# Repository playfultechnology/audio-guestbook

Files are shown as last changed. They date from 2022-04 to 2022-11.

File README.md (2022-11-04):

# audio-guestbook
The audio guestbook is a converted telephone handset that guests can use to leave recorded messages at weddings, parties and other events, as sold by companies such as "After the Tone", "Fête Fone", "Life on Record", "At the Beep", and others.

Watch the full step-by-step tutorial on how to use the code here to build your own at https://youtu.be/dI6ielrP1SE
 
 ---
## Disabled MTP during recording
In some cases, the MTP capability (allowing file transfer without removing the SD card) seems to interfere with recording. MTP medium-change checking is thus _disabled_ during recording. A suitable message is sent to the serial monitor so you can see when it's been enabled.
## Audio tweaks
### Background
The "modifications by h4yn0nnym0u5e, October 27th 2022" work significantly better if the audio library is "tweaked" to use larger data blocks and thus less-frequent audio updates. This allows more time for an SD card write before an interrupt is missed and audio data are lost.
### Installation method
Unfortunately, "installation" is a bit messy, but you only have to do it once (unless you update your Arduino IDE or Teensyduino). The guestbook sketch folder contains two Arduino architecture configuration files, `boards.local.txt` and`platform.txt`. These must be used to update your existing configuration files; in Windows systems these will typically be in `C:\Program Files (x86)\Arduino\hardware\teensy\avr` [todo: where are they on Linux and Mac?].

Before you do anything else, **_back up the existing configuration files_**! Then, make sure all running copies of the Arduino IDE are closed.

The content of `boards.local.txt` should be merged with the existing file; if you don't have one, just copy this file in.

You can either replace the existing `platform.txt` with the new one, or if the existing one looks _very_ different, try to edit it to include all four references to `build.flags.audio`, in similar locations to those found in the replacement file. 

Once the configuration files have been amended, run the Arduino IDE and look at the Tools menu. All being well, you will see a new "Audio tweaks" setting available, with options `Normal` and `Bigger blocks (256 samples)`.
### In use
Open the audio guestbook sketch, ensure you have the correct Teensy options set, and set "Audio tweaks" to the `Bigger blocks (256 samples)` option. Upload as usual, and check that there's a message on the Serial console which says "Audio block set to 256 samples". If this is present, the tweaks installation is successful, and you should find your audio recordings less prone to glitches and dropouts. You should still use a decent SD card, and format it "properly" - there's plenty of guidance in the Teensy forum.

For most audio projects, leave Audio tweaks set to `Normal`, as the audio library isn't fully tested with 256-sample blocks.

_DO NOT_ copy the `play_wav_sd.cpp` and `.h` files to your Audio library: They _should_ appear as extra tabs in your Arduino IDE, but are _only_ of use for this project and _will_ break other audio applications using SD playback!

## Technical stuff
### Tweaks
As noted above, the tweaks work by increasing the number of audio samples in an "audio block" from 128 to 256. This means that audio updates run every 5.8ms rather than the standard 2.9ms, with the consequence that an SD write can take nearly 12ms before an update is "lost". It would be better to figure out how to prevent the SD card write from masking interrupts, but I'm clearly not quite smart enough...

The audio library AudioPlaySdWav object is unfortunately one of those that doesn't work well with anything other than a standard 128-sample audio block. Therefore, a (renamed) copy which _does_ work properly is now included within the sketch folder, and used instead of the stock object.
### Instrumented SD writes
You can monitor the time taken for SD card writes by defining the symbol `INSTRUMENT_SD_WRITE`. This is disabled by default, but a line ready for easy editing can be found near the top of the main sketch file. Ideally writes should take significantly less than 6000µs without audio tweaks, or 12000µs with them. Worst-case write times are output every 0.25s.

---
**Modifications by h4yn0nnym0u5e, October 27th-30th 2022:**
* modifications to improve recording reliability:
  * write in larger chunks
  * use bigger audio blocks to increase update period
  * disable MTP medium change checks during recording
* corrected WAV header writes to make chunk lengths correct
* optional code to determine SD card write time

**Modifications by DD4WH, August 1st, 2022:**
* recordings are now saved as WAV files
* recordings on the SD card can be accessed via USB, no more need to take out the SD card
* code modifications for a telephone with closing contact as the handheld is being lifted
* playback only plays the very last recorded file, not ALL the files ever recorded
* does not play the greeting message again when you want to listen to your recordings
* some bugfixes and warnings eliminated
* do not forget that your greeting message has to be recorded as a WAV with a sample rate of 44.1ksps, otherwise it is not played
* compile the code with CPU speed 150MHz, this can save a lot of battery power (reduction by about 70%)

**DD4WH hardware:**
* telephone model "POST FeTAp 611-2a", built about 1972
* Teensy 4.0
* Audio Board for Teensy 4
* AOM5024 electret low noise microphone capsule (the original mic capsule was thrown away)
* push button with red knob
* microUSB to USB-A cable 
* shielded microphone cable

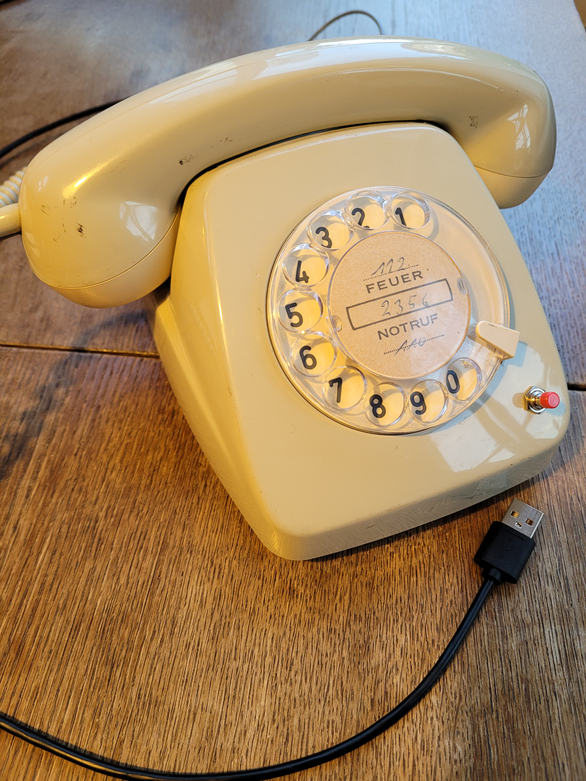
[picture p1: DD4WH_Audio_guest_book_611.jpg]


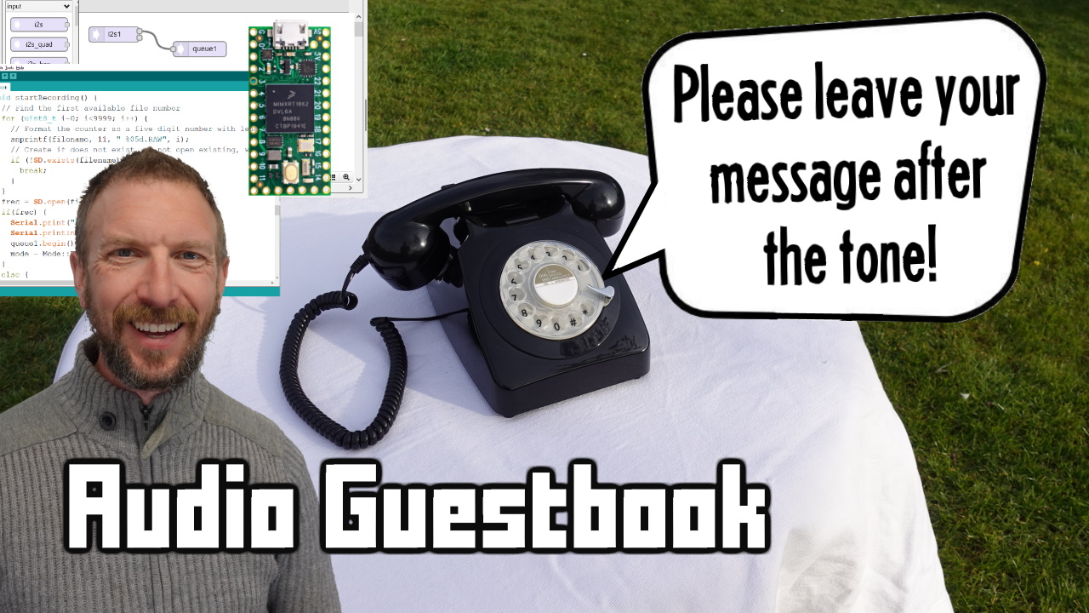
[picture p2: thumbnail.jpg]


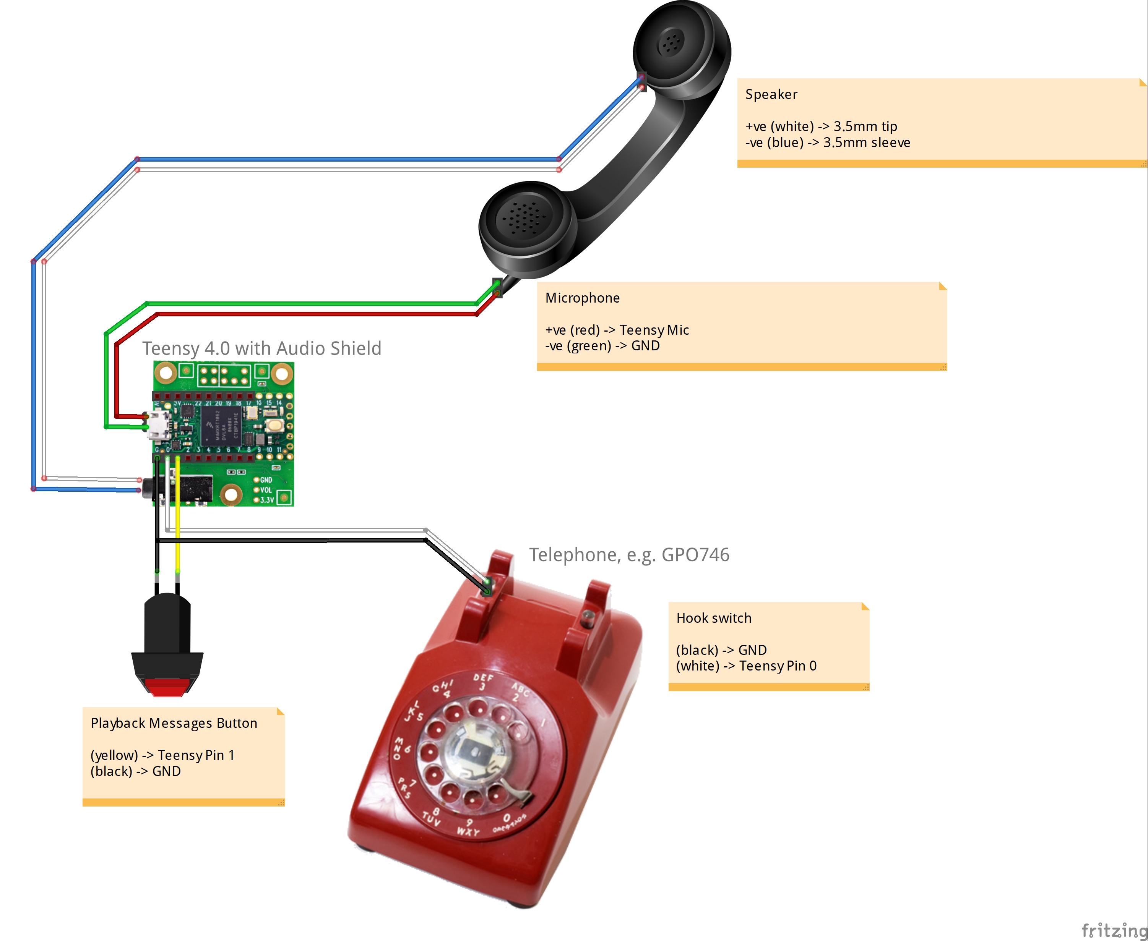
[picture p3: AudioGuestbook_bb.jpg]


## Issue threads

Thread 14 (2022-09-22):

No Sound from speaker

TOPD3, 2022-09-22:

nrich50, 2023-02-17:
were you ever able to fix this issue? im currently having the same problem

Closed 2022-09-22.

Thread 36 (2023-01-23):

Several Problems and Solutions I Found During My Build

mpetti1816, 2023-01-23:
It took me a lot of hunting around to fix some of the code issues I was encountering and I'd thought I'd explain my solutions to those of you who are struggling with the same problems. The answers were pulled from this project's main page, the "Closed Issues" board, and a few other places on the internet, but here they are consolidated.

My experiences only pertain to the Github code for this project as of January 22, 2023 and the specific hardware/software that I used.

**My hardware:**
Teensy 4.0 board
Teensy4_AUDIO Audio Shield
Momentary pushbutton
Vintage telephone

**My software:**
Arduino IDE 1.8.19
Teensyduino 1.57 using Windows installer

**First steps:** I did all of the installation adjustmets included on the audio-guestbook Github main page, such as
- copied boards.local.txt
- copied platform.txt
- Changed "Audio tweaks" to "Bigger blocks (256 samples)"

I then had several compiling errors that I had to hunt around for solutions to

**Problem:**
AudioPlaySdWavX does not name a type
&
'playWav1' was not declared in this scope
**Solution:**
Inside your sketch, go to the "Sketch" dropdown at the top, choose "Add File" and add play_wav_sd.cpp and repeat with play_wav_sd.h files that were in the Github code download.
Leave those tabs open, then try Verifying your sketch and you should lose those errors.

**Problem:**
Multiple libraries were found for "SD.h"
**Solution**:
I cut/pasted the folder 'C:\Program Files (x86)\Arduino\libraries\SD' out of the Arduino libraries directory and saved it elsewhere on my computer for safe keeping. Now, the only 'SD' folder should be under Arduino\hardware\teensy\avr\libraries\

**Problem:**
Compiling error involving SerialFlash.h
**Solution:**
Re-ran the TeensyDuino installer and added the 'SerialFlash' library

**Problem:**
Multiple errors involving MTP_Teensy.h
**Solution:**
Download the Github code from https://github.com/KurtE/MTP_Teensy and unzip the folder into 'C:\Program Files (x86)\Arduino\libraries\'
Then, in your Arduino sketch, select from the dropdowns at the top "Tools > USB Type > Serial + MTP Disk (Experimental)"

**Problem:**
Audio was clipping (breaking up) during playback after I got everything "working"
**Solution:**
There are two volume adjustments in the code that I fiddled with. Use CTRL+F in the code to find "sgt15000_1.volume(0.95)". The 0.95 is 95% volume on the headset speaker, which was too loud. I dropped it down to 0.7 and it stopped clipping on playback.
I also adjusted the "sgt15000_1.micGain(5)", which is how loud the microphone on the headset is recorded in the file. I dropped it to (4) because the recordings sounded blown out.

**Problem:**
My greeting message wasn't playing back, I would just get a single "beep" when I lifted the handset
**Solution:**
I downloaded Audacity and opened my greeting message, then exported it using 44.1kHz and 16-bit PCM as a new WAV file. I also had a stereo recording, so I had to delete one of the tracks to make it "mono". That fixed the playback problem.

**Problem:**
The code compiled correctly (finally), but the handset wasn't responding properly and I was hearing a constant clicking noise in the speaker.
**Solution:**
My phone had a lot of shared terminals in the internal wiring. I disconnected all of the wires from the phone's terminals and directly wired each wire from the speaker/microphone/handset contact/pushbutton to the inputs/outputs of my Teensy board. This solved the clicking issue and after troubleshooting my code, it also solved the audio issues.

fivefortyfour, 2023-01-23:
Nice, thanks for your update! Where do you put the greeting audio file?

BrandonJam, 2023-01-23:
Ok.  So I have board soldered. Code compiled and uploaded to the Board.  I add power to the Board and I hear a beep.  After that, I get nothing.  Not sure what the issue is.  Is there a way to see a log of the steps of code the Board is going through?  Maybe then I can determine where my issue is.

mpetti1816, 2023-01-23:
> Ok. So I have board soldered. Code compiled and uploaded to the Board. I add power to the Board and I hear a beep. After that, I get nothing. Not sure what the issue is. Is there a way to see a log of the steps of code the Board is going through? Maybe then I can determine where my issue is.

That initial beep is an indication that it has power and is running (at least that's what it seems like, mine does the same beep upon power). If you look under the Tools menu, there is something called the Serial Monitor. When you open that and run your board, there are sections of the code that will print out what is going on while it's running. I used that to troubleshoot a few wiring problems I had.

BrandonJam, 2023-01-23:
I just did Serial Monitor.  It keep saying "unable to access SD card".  SD card is definitely present though.

mpetti1816, 2023-01-23:
> I just did Serial Monitor. It keep saying "unable to access SD card". SD card is definitely present though. It is in the same way after programming the board.

I am no where near an expert on this stuff, but a couple things that come to mind. Ensuring your MTP_Teensy libraries were put in the right folders and that "Serial + MTP Disk (Experimental)" was selected (both in my initial post). The other thing to check is that your SD card is not larger than 2GB. That limitation is mentioned at the bottom of this page https://www.pjrc.com/store/teensy3_audio.html

Other than that, I can't think of anything else, so good luck Googling or having someone else chime in.

BrandonJam, 2023-01-23:
I saw another Issue down below that said it was the pin locations with Rev D of the Audio Shield.  I changed those to match the Rev D diagram, but still getting the same message.

cpereirauy, 2023-01-24:
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

I formatted my SC card (32gb Samsung) to exfat, not saying that would solve your issue, but worth trying.
Another thing, where are you inserting your SD card? Teensy or Audio Shield? Try swithching them

BrandonJam, 2023-01-25:
Did you select the port under Tools?

On Tue, Jan 24, 2023 at 6:08 PM fivefortyfour ***@***.***>
wrote:

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
--
Brandon Jesse
Owner/Booth Attendant
JamBooth Photos
www. JamBoothPhotos.com
757-524-1211

BrandonJam, 2023-01-25:
I am using Teensy 4.0 so SD only in Audio Shield.

I ended up using a different fork version of the code and it worked fine
with my sd card as is. Weird.

On Tue, Jan 24, 2023 at 4:27 PM C.PereiraUY ***@***.***>
wrote:

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
--
Brandon Jesse
Owner/Booth Attendant
JamBooth Photos
www. JamBoothPhotos.com
757-524-1211

fivefortyfour, 2023-01-25:
Here's my error regarding the Serial port issue.... I have tried both the Serial+MPT Disk (experimental) and MTP Disk (experimental)

Arduino: 1.8.19 (Windows 10), TD: 1.57, Board: "Teensy 4.0, MTP Disk (Experimental), 600 MHz, Faster, US English, Bigger blocks (256 samples)"

C:\Program Files (x86)\Arduino\libraries\MTP_Teensy\src\MTP_Teensy.cpp: In member function 'uint32_t MTP_class::GetObjectInfo(MTP_class::MTPContainer&)':

C:\Program Files (x86)\Arduino\libraries\MTP_Teensy\src\MTP_Teensy.cpp:523:34: warning: unknown option after '#pragma GCC diagnostic' kind [-Wpragmas]

   #pragma GCC diagnostic ignored "-Wformat-truncation" /* Or "-Wformat-truncation" */

                                  ^

Memory Usage on Teensy 4.0:

  FLASH: code:106616, data:13540, headers:8864   free for files:1902596

   RAM1: variables:18912, code:104024, padding:27048   free for local variables:374304

   RAM2: variables:50528  free for malloc/new:473760

Serial port not selected.

Invalid library found in C:\Program Files (x86)\Arduino\libraries\SDBackup: no headers files (.h) found in C:\Program Files (x86)\Arduino\libraries\SDBackup

This report would have more information with
"Show verbose output during compilation"
option enabled in File -> Preferences.

fivefortyfour, 2023-01-25:
Finally, all working!

rich-day, 2023-01-25:
I had to amend my SD card pins in the code as I am using Audio Shield Rev D - this ended up working (as well as making sure my pins were connected accordingly)
`#define SDCARD_CS_PIN    10
#define SDCARD_MOSI_PIN  11
#define SDCARD_SCK_PIN   13`

BrandonJam, 2023-01-25:
Thanks, Rich.  So, I have done this with a few different variations of the code, and also by changing the pin numbers in the code for those different variations, because I too saw that the PIN locations for the T4.0/Audio Shield were different than what people were using.

https://www.pjrc.com/store/teensy3_audio.html

I ended up getting the DD4WH fork code to work WITHOUT changing the pin locations, which confuses me somewhat as to why that worked if the pin locations are off.

Question back to you though... so I know how to easily change the pin locations in the code, but I wasn't thinking about physically changing the pin connections on the board.  I was under the impression that when the T4.0 and Audio Shield were stacked together, then that is where the pins lined up appropriately based on the link above.  Can you touch on this part a little more?  Maybe even a pic of your board?

rich-day, 2023-01-25:
Sorry, to clarify, I just meant confirming that my pins (10,11,13 in this case) were soldered well and that the board was stacked correctly (e.g. not misaligned or upside down etc). I am by means no expert on this, I've just recently completed this project and ran in to similar problems so just sharing my learnings.

Glad to hear you got it working however!

DevlinDiener, 2023-02-13:
> I am using Teensy 4.0 so SD only in Audio Shield. I ended up using a different fork version of the code and it worked fine with my sd card as is. Weird.
Can I ask which fork you ended up using? I am facing the same problem.

BrandonJam, 2023-02-14:
the fork version from @DD4WH

fivefortyfour, 2023-02-19:
I'm recording my wav files to sd card but when I plug teensy into laptop with usb cable, I can't play the files as it says they're in use? I can't copy them either. How do you use them?  I want to access them with usb cable and not take out the sd card.

TWK-Nattttttttt, 2023-02-21:
I'm a little confused. I downloaded the MTP_Teensy documents that you said to and put them in the libraries folder, but I'm still getting "'MTP' was not defined in this scope."

The extent of my knowledge with code is drawing a circle on Khan Academy, so I'd appreciate any help I can get *imagine there is a laughing emoji here*

fivefortyfour, 2023-03-05:
I have a phone that has been working fine. Now it seems to have stopped
working. I don't get the 4 beeps when I hang up the phone?
Anyone have this problem?

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

markmak77, 2023-03-12:
Does anyone know if the author (@alastaira) is still accepting Pull Requests? It'd be nice to add something like this to a "Troubleshooting" section of the readme...

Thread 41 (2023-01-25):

Clarify recording wav files saving to SD card

BrandonJam, 2023-01-25:
Have one of the fork versions (DD4WH) of this code working seemingly fine.

One main question I have related to the saving of the recording wav files to the SD card...
-I have been testing my audio guestbook while connected to my PC for now.
-It seems that the recordings don't save to my SD card right away.  I have the SC card open while operating so I can watch this.
-They do seem to be saving to memory because I can play them back on the phone after recording.
-Once I disconnect the phone from the PC and reconnect it, then the files that were recorded prior appear on the SD card as viewed from the PC.

Is this expected behavior, or should the files be visible as saved on the SD card in relatively real time?

BrandonJam, 2023-01-30:
@DD4WH would you be able to provide some insight for me?  Thanks.

DD4WH, 2023-02-01:
Your test conditions are not valid :-).

* Use the latest software version from my github
* never try to record while the Telephone is connected to your PC !
* use a USB power bank or a power supply to power the telephone
* Record
* unplug power from the telephone
* plug the telephone into your PC
* the recordings should be on your SD card and visible in the file explorer of your PC

YOU CANNOT RECORD WHILE THE TELEPHONE IS PLUGGED INTO THE PC

BrandonJam, 2023-02-01:
@DD4WH Thank you.

I am using your latest version.  Also, do you mean to say "you should not record while the telephone is plugged into the PC", rather than "you cannot"?  I read them differently, and I am pretty sure you can record when it is connected to the PC (it will record), but maybe I/we shouldn't be as it causes potential issues.

While I have you, I made another issue post where I was trying to clarify the correct external power voltage to use.  In the documentation, I see 3.3v, but I see a bunch of people saying 5v.  Thoughts?

DD4WH, 2023-02-01:
The Teensy documentation is pretty clear where to apply which voltage :-). Read carefully on the PJRC page ;-).

BrandonJam, 2023-02-01:
@DD4WH

So, based on below... if I am now reading correctly, if you power by USB, you can use 5v, since the board converts 5v to 3.3v when using the VUSB/VIN Pin.  I think I read that too fast the last time around.  Can you confirm I am reading and understanding correctly now?  Would be appreciated.

**USB Power**
Normally Teensy is powered by your PC or USB hub, through a USB cable. The **_USB power arrives at the VUSB pin, which is connected VIN and powers the entire board._**
**VIN Pin**
When USB power is not used, 5V power may be applied to the VIN pin. Because VIN & VUSB are connected, power should not be applied to VIN while a USB cable is used, to prevent the possibility of power flowing back into your computer. Alternately, a pair of pads on the bottom side may be cut apart, to separate VUSB from VIN, allowing power to be safely applied while USB is in use. (TODO: VUSB-VIN pads photo, right side)
**3.3V Power**
Teensy 4.0 **_has a voltage regulator which reduces the 5V VUSB / VIN power to 3.3V for use by the main processor_** and most other parts. Additional circuitry may be powered from the 3.3V pin. The recommended maximum for external 3.3V usage is 250mA. Teensy 4.0 is not meant to receive power on its 3.3V pin, but this can be done with special modificaton.

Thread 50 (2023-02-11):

Volume issues & Regular ticking sounds on both playback & recorded files

avierose, 2023-02-11:
I've just built the project and confirmed that the logic is working correctly for my phone via serial monitor.

The first issue I'm having is that the playback volume through the handset is very quiet, almost can't hear it in a quiet room. I have tried increasing the value in
```
sgtl5000_1.volume(0.95)
```
With no noticeable effect.

The second issue I'm having is that there is a regular ticking sound (4-5/second) over the handset speaker which is also reflected in the recorded .wav files. I'm guessing some connection is bridged but I can find any bad solder joints

avierose, 2023-02-12:
I've solved the ticking sound, it seems like there are some dodgy capacitors on my telephones circuit board, so I've connected all 4 wires from the handset directly to the Teensy+Audio Shield.

The volume of the playback is still far too quiet to be of any use though. I did try to increase the value in:
`mixer.gain(0, 1.0f);`
`mixer.gain(1, 1.0f);`
but that just introduced distortion without any increase in volume.

avierose, 2023-03-01:
Seems that the speaker module in my phone (Tele 8746) cannot be driven by the Teensy/Audio board. I ended up taking a speaker out of an old cheap headphone set which now works perfectly.

Closed 2023-03-01.

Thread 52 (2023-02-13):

Unable to access the SD card

DevlinDiener, 2023-02-13:
After compiling and uploading the code successfully my board doesn't do anything when hooked up to the phone. Naturally I plugged it in and ran the serial monitor to see if I could troubleshoot. The monitor continuously prints the message

"Unable to access the SD card"

I have the SD card slotted directly onto the audio shield's card slot. I verified the SD card compatibility as well so I'm not sure if this is a code error or a hardware issue. Any help is appreciated!

nrich50, 2023-02-16:
did you ever fix this issue i am having this problem aswell and nothing i have done has fixed it

rhilyard, 2023-02-18:
I think a lot of us are having this same issue. I hope someone can tell us how to fix this. I have tried everything.

BrockV2, 2023-02-18:
Makes 4 of us, I have also run out of ideas. Will keep trying.

nrich50, 2023-02-18:
So after messing with this thing for over 24 hours in my case I had to change the ports since I am using the REV D audio shield and use a different SD card. Idk why my other one wouldn't work but once I put a new one in it was able to access. Bit since I have solved that problem I still have no sound coming from the speaker and no input from the mic

Praxxxer, 2023-02-18:
@nrich50 I'm also using a REV D2 audio shield. What did you change your SDCARD_MOSI_PIN values to?

BrockV2, 2023-02-19:
@Praxxxer

Please check the PIN numbers you have quoted as they do not match the values on the teensy drawings.

To help troubleshoot, can you please confirm if you are using Teensy 4.0 or 4.1?

Please also check the pins for the hook switch as it’s common to see people wire it to ground and 0, not 0 and 1.

DevlinDiener, 2023-02-21:
Update:

I've fixed the "unable to access SD card" issue. For reference, I'm using a Teensy 4.0 and REV D2 audio shield. Here are the pins I've assigned:

- #define SDCARD_CS_PIN    10
- #define SDCARD_MOSI_PIN  7
- #define SDCARD_SCK_PIN   14

I occasionally get this issue during testing (likely due to improper connection), but it will usually fix itself after a reboot.

The problem I have now is my microphone line is not picking up any input, and my speaker doesn't produce output. I assume this is due to a bad soldering job on a few connections. I took a break from this project but am picking it back up. I'll update you all again with any useful info once I've fixed the issue.

rhilyard, 2023-02-21:
Which fork is everyone using? I have the teensy 4.0 and Rev D2 audio shield. I used
    #define SDCARD_CS_PIN 10
    #define SDCARD_MOSI_PIN 7
    #define SDCARD_SCK_PIN 14
but that didn
t help at all.

nrich50, 2023-02-22:
I believe I am using the fork @DD4WH has. Have you tried a different SD card and making sure it's formatted. I think it needs to be exFAT but I'm not 100% sure. For me I changed all those pins and it still was not working until I got a new SD. And this mag be stupid but I found myself doing this. If you don't have the teensy directly mounted to the audio shield. Make sure the GND on the teensy is also connected to the audio shield GND. I am completely new to all of this so many mistakes have been made lol

nrich50, 2023-02-22:
Still having the issue of no sound or mic input. I thought maybe I messed up the board but since many people are having it then it must be either a bad batch of audio shields or a error in programming

rhilyard, 2023-02-22:
I have used several different types of sd cards  The gnd is connected to the audio shield. I'm completely at a lost on what to do!!

nrich50, 2023-02-24:
i used this for my pins and added a extra one that is not in the original program. it may not fix your issue but its worth a shot.

#define SDCARD_CS_PIN    10
#define SDCARD_MSIO_PIN    12
#define SDCARD_MOSI_PIN  11
#define SDCARD_SCK_PIN   13

rhilyard, 2023-02-24:
@nrich50 Thanks just gave it a try and it didn't help.  Thanks for the suggestion

kyuubii, 2023-02-25:
I also face the same issue "Unable to access the SD card".
I use a "Teensy 4.0" with an "Audio Shield Rev D2".
I tried to:
- use different SD cards (from 512 MB to 64 GB)
- use FAT, FAT32, exFAT, NTFS formats
- use different pins (10, 11, 12, 13)

markmak77, 2023-03-16:
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

@DevlinDiener , Thank you for confirming that these are the correct pin associations for Teensy 4.0 + the Rev D2 audio shield. Could you also please share what you have your micro SD card formatted to?

markmak77, 2023-03-17:
**Update: IT WORKS!**
First of all, I'd like to confirm that the pins listed above by DevlinDiener are indeed the correct ones if you're using a Teensy 4.0 + Rev D2 audio shield - my micro SD card initialized successfully and was recognized by the controller using those exact pins. I'm using a class 10 Sandisk MicroSD card, 32 GB, formatted as FAT32 (did a full format, not quick, just in case, although that shouldn't really affect anything in theory).

Secondly, I'd like to suggest to everyone who's had this problem (or will have it in the future): **CHECK YOUR CONNECTIONS/SOLDER JOINTS**! A post [here](https://forum.pjrc.com/threads/70679-Teensy-4-0-Audio-Board-Rev-D-SD-card-problem) got me thinking this might be the issue, and it seems it was.

I'd soldered headers onto both the Teensy (male) and the audio shield (female), _except_ for the 3 pins on the left side (GND, 0, 1) to leave them available for the button(s). Now, I know the audio shield needs a GND, but I thought it would be ok with the one on the other side, between Vin (aka 5V) and 3.3V (aka 3V), but apparently not... And, to make sure I didn't have any cold solder joints, I took my soldiering iron to each pin (on both the Teensy and the shield) once again, and it seems those 2 actions solved this issue for me.

PS: before doing any additional soldering, don't forget to first remove the SD card from the shield.

(cc @nrich50 , @rhilyard , @Praxxxer , @kyuubii )

markabruce, 2023-03-17:
Hi everyone,

I am not yet 100% sure why, but for me the `#ifdef TEENSY_41` seemed to be the culprit...

I have a Teensy 4.0 and a Audio Shield Rev D2.

Remove the two references of `#ifdef TEENSY_41`.

**So when defining pins...**

```
#ifdef TEENSY_41
#define SDCARD_CS_PIN    BUILTIN_SDCARD
#else
#define SDCARD_CS_PIN    10
#endif
```

becomes:
```
// Define pins used by Teensy Audio Shield
#define SDCARD_CS_PIN    10
#define SDCARD_MOSI_PIN  7
#define SDCARD_SCK_PIN   14
```

**When setting MOSI and SCK pins...**

```
#ifndef TEENSY_41   // assumes that you are using the SD card slot of the AUDIO BOARD
  SPI.setMOSI(SDCARD_MOSI_PIN);
  SPI.setSCK(SDCARD_SCK_PIN);
#endif
```

becomes:

```
  SPI.setMOSI(SDCARD_MOSI_PIN);
  SPI.setSCK(SDCARD_SCK_PIN);
```

markmak77, 2023-03-17:
@markabruce , that's probably because you had Teensy 4.1 selected in the Arduino IDE under Tools -> Board: "Teensy x.x". To change it (i.e. define TEENSY_40 instead of TEENSY_41), select Tools -> Board: "Teensy x.x" -> Teensyduino -> Teensy 4.0.

markabruce, 2023-03-18:
I am pretty sure I had 4.0 selected, I'll double check tomorrow.

markabruce, 2023-03-18:
Here:

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

I have Board: Teensy 4.0 and yet the `IFNDEF TEENSY_41` must somehow skip settings the pins, maybe a bug with my version of Arduino IDE (1.8.19), or the Teensy installer...

I just copied what `File > Examples > Audio > HardwareTesting > SdCardTest` was doing, which is what PRJC recommend: https://www.pjrc.com/store/teensy3_audio.html

The IFNDEF is saying if TEENSY_41 is NOT defined, then set the SPI - so I've not idea how the software must think TEENSY_41 is defined, is it some sort of global variable set by one of the libraries? Can't find any docs on it...

BrockV2, 2023-03-18:
Has to be defined in the sketchbook code not the menu.

On 18 Mar 2023, at 08:36, markabruce ***@***.***> wrote:

Here:

[image]<https://user-images.githubusercontent.com/10707880/226093869-4a1a1430-52c8-4878-936c-92de82535e80.png>

I have Board: Teensy 4.0 and yet the IFNDEF TEENSY_41 must somehow skip settings the pins, maybe a bug with my version of Arduino IDE (1.8.19), or the Teensy installer...

I just copied what File > Examples > Audio > HardwareTesting > SdCardTest was doing, which is what PRJC recommend: https://www.pjrc.com/store/teensy3_audio.html

The IFNDEF is saying if TEENSY_41 is NOT defined, then set the SPI - so I've not idea how the software must think TEENSY_41 is defined, is it some sort of global variable set by one of the libraries? Can't find any docs on it...

—
Reply to this email directly, view it on GitHub<https://github.com/playfultechnology/audio-guestbook/issues/52#issuecomment-1474773864>, or unsubscribe<https://github.com/notifications/unsubscribe-auth/A57QTTNDGKCKTAXUUBJXR2LW4VXY3ANCNFSM6AAAAAAU2XVQXU>.
You are receiving this because you commented.Message ID: ***@***.***>

markabruce, 2023-03-18:
> Has to be defined in the sketchbook code not the menu.

Aha! Thank you, I was being a fool and I hadn't removed #define TEENSY_41, I thought I had searched for every reference to it, but obviously didn't! The forked code even mentions to do this in the [README.md](https://github.com/DD4WH/audio-guestbook/blob/main/README.md).

I suspect though, that this could be the issue a lot of other people are facing. Search for every line of `TEENSY_41` and comment it out or remove it, it is not required if you're on a TEENSY 4.0.

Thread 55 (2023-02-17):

no sound from speaker or input from mic

nrich50, 2023-02-17:
I have the wire from the center of the mic connected to the mic pin and the outside sleve to the gnd pin (i have tried reversing them) but i still dont have any audio on my recordings.

and i do not hear a beep or my greeting once the hook switch is made. serial monitor says that it is prompting then switches to recording but i hear nothing. i used a 3.5mm headphone jack and have tried reversing both the tip and the sleeve wires but still nothing

i know my speaker and mic are working because i can hear a buzz from the speaker when i touch the wires and i put a meter across the mic and when i talk the resistance changes with how loud i speak.

Praxxxer, 2023-02-18:
I am having the same issue.

nrich50, 2023-02-18:
@Praxxxer let me know if you figure it out and I will do the same. I ordered a new audio shield and I got another aux breakout board maybe that's all

Praxxxer, 2023-02-18:
I just ordered a new aux breakout board too. I really want to avoid buying a whole new shield. Are you using those block connectors? If so, what are your speaker connections reading with the multi-meter?

cpereirauy, 2023-02-22:
same here, got a couple of vintage phones and even ordered new mic and speakers, but still the same results.
I was hoping by now I would have this in working order

nrich50, 2023-03-06:
Has anyone found a solution yet?

EricaFitzz, 2023-03-09:
Same issue here, its writing the recordings to the SD but no sound

EricaFitzz, 2023-03-10:
Check that your mic and speaker wires are in the correct places, mine were swapped. Working great now!

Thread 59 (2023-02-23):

Noticed something..

z3gineer, 2023-02-23:
Got the code to work. Everything functions perfectly!

However, I noticed that if you hang-up the phone at the exact time as the "beep" that comes after the greeting message, the program continues to record and does not recognize the phone is placed back on the hook.

Anyone know what can be done to fix this?

I placed a maximum duration limit for recordings in the code to avoid an accidental long recording, but I would still like to solve the problem.

SehlingS, 2023-02-23:
Hi,

i'm sorry i have no solution for you.
But can you please share your way to implement a duration limit for the recordings.

Best regards
Sascha

Gaunajr, 2023-02-24:
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

What line did you put a limit recording time at? I noticed that as well and it happened where a message was left for an hour due to this same problem.

Thanks in advance.

z3gineer, 2023-02-24:
So there's 3 sections you need to add code (see pictures below)

the "120000" is the limit in milliseconds (= 2 min)

Also, my handset hook switch was the "reversed version", so my code will look slightly different than the original code posted.

let me know if this helps.

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

Gaunajr, 2023-02-28:
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

Thank you for the reply.
And to clarify, 120000 should be entered in lines 84, 243, and 255. Or just on 255 like shown on the screenshots?

Gaunajr, 2023-02-28:
I added the timer to the code but it is not functioning. Recording time goes over the 2 min mark. By looking at the code below do you see anything that went wrong?

Thank you in advance.

[code]
/**
 * Audio Guestbook, Copyright (c) 2022 Playful Technology
 *
 * Tested using a Teensy 4.0 with Teensy Audio Shield, although should work
 * with minor modifications on other similar hardware
 *
 * When handset is lifted, a pre-recorded greeting message is played, followed by a tone.
 * Then, recording starts, and continues until the handset is replaced.
 * Playback button allows all messages currently saved on SD card through earpiece
 *
 * Files are saved on SD card as 44.1kHz, 16-bit, mono signed integer RAW audio format
 * --> changed this to WAV recording, DD4WH 2022_07_31
 * --> added MTP support, which enables copying WAV files from the SD card via the USB connection, DD4WH 2022_08_01
 *
 *
 * Frank DD4WH, August 1st 2022
 * for a DBP 611 telephone (closed contact when handheld is lifted) & with recording to WAV file
 * contact for switch button 0 is closed when handheld is lifted
 *
 * GNU GPL v3.0 license
 *
 */

#include <Bounce.h>
#include <Audio.h>
#include <Wire.h>
#include <SPI.h>
#include <SD.h>
#include <TimeLib.h>
#include <MTP_Teensy.h>
#include "play_sd_wav.h" // local copy with fixes

// DEFINES
// Define pins used by Teensy Audio Shield
#define SDCARD_CS_PIN    10
#define SDCARD_MOSI_PIN  7
#define SDCARD_SCK_PIN   14
// And those used for inputs
#define HOOK_PIN 0
#define PLAYBACK_BUTTON_PIN 1

#define noINSTRUMENT_SD_WRITE

// GLOBALS
// Audio initialisation code can be generated using the GUI interface at https://www.pjrc.com/teensy/gui/
// Inputs
AudioSynthWaveform          waveform1; // To create the "beep" sfx
AudioInputI2S               i2s2; // I2S input from microphone on audio shield
AudioPlaySdWav              playWav1; // Play 44.1kHz 16-bit PCM greeting WAV file
AudioRecordQueue            queue1; // Creating an audio buffer in memory before saving to SD
AudioMixer4                 mixer; // Allows merging several inputs to same output
AudioOutputI2S              i2s1; // I2S interface to Speaker/Line Out on Audio shield
AudioConnection patchCord1(waveform1, 0, mixer, 0); // wave to mixer
AudioConnection patchCord3(playWav1, 0, mixer, 1); // wav file playback mixer
AudioConnection patchCord4(mixer, 0, i2s1, 0); // mixer output to speaker (L)
AudioConnection patchCord6(mixer, 0, i2s1, 1); // mixer output to speaker (R)
AudioConnection patchCord5(i2s2, 0, queue1, 0); // mic input to queue (L)
AudioControlSGTL5000      sgtl5000_1;

// Filename to save audio recording on SD card
char filename[15];
// The file object itself
File frec;

// Use long 40ms debounce time on both switches
Bounce buttonRecord = Bounce(HOOK_PIN, 40);
Bounce buttonPlay = Bounce(PLAYBACK_BUTTON_PIN, 40);

// Keep track of current state of the device
enum Mode {Initialising, Ready, Prompting, Recording, Playing};
Mode mode = Mode::Initialising;

float beep_volume = 0.04f; // not too loud .04 :-)

uint32_t MTPcheckInterval; // default value of device check interval [ms]

//Timer
unsigned long startTime = 0;

// variables for writing to WAV file
unsigned long ChunkSize = 0L;
unsigned long Subchunk1Size = 16;
unsigned int AudioFormat = 1;
unsigned int numChannels = 1;
unsigned long sampleRate = 44100;
unsigned int bitsPerSample = 16;
unsigned long byteRate = sampleRate*numChannels*(bitsPerSample/8);// samplerate x channels x (bitspersample / 8)
unsigned int blockAlign = numChannels*bitsPerSample/8;
unsigned long Subchunk2Size = 0L;
unsigned long recByteSaved = 0L;
unsigned long NumSamples = 0L;
byte byte1, byte2, byte3, byte4;

void setup() {

  Serial.begin(9600);
  while (!Serial && millis() < 5000) {
    // wait for serial port to connect.
  }
  Serial.println("Serial set up correctly");
  Serial.printf("Audio block set to %d samples\n",AUDIO_BLOCK_SAMPLES);
  print_mode();
  // Configure the input pins
  pinMode(HOOK_PIN, INPUT_PULLUP);
  pinMode(PLAYBACK_BUTTON_PIN, INPUT_PULLUP);

  // Audio connections require memory, and the record queue
  // uses this memory to buffer incoming audio.
  AudioMemory(60);

  // Enable the audio shield, select input, and enable output
  sgtl5000_1.enable();
  // Define which input on the audio shield to use (AUDIO_INPUT_LINEIN / AUDIO_INPUT_MIC)
  sgtl5000_1.inputSelect(AUDIO_INPUT_MIC);
  //sgtl5000_1.adcHighPassFilterDisable(); //
  sgtl5000_1.volume(0.7);

  mixer.gain(0, 1.0f);
  mixer.gain(1, 1.0f);

  // Play a beep to indicate system is online
  waveform1.begin(beep_volume, 440, WAVEFORM_SINE);
  wait(1000);
  waveform1.amplitude(0);
  delay(1000);

  // Initialize the SD card
  SPI.setMOSI(SDCARD_MOSI_PIN);
  SPI.setSCK(SDCARD_SCK_PIN);
  if (!(SD.begin(SDCARD_CS_PIN)))
  {
    // stop here if no SD card, but print a message
    while (1) {
      Serial.println("Unable to access the SD card");
      delay(500);
    }
  }
    else Serial.println("SD card correctly initialized");

  // mandatory to begin the MTP session.
    MTP.begin();

  // Add SD Card
//    MTP.addFilesystem(SD, "SD Card");
    MTP.addFilesystem(SD, "Kais Audio guestbook"); // choose a nice name for the SD card volume to appear in your file explorer
    Serial.println("Added SD card via MTP");
    MTPcheckInterval = MTP.storage()->get_DeltaDeviceCheckTimeMS();

    // Value in dB
//  sgtl5000_1.micGain(15);
  sgtl5000_1.micGain(20); // much lower gain is required for the AOM5024 electret capsule

  // Synchronise the Time object used in the program code with the RTC time provider.
  // See https://github.com/PaulStoffregen/Time
  setSyncProvider(getTeensy3Time);

  // Define a callback that will assign the correct datetime for any file system operations
  // (i.e. saving a new audio recording onto the SD card)
  FsDateTime::setCallback(dateTime);

  mode = Mode::Ready; print_mode();
}

void loop() {
  // First, read the buttons
  buttonRecord.update();
  buttonPlay.update();

  switch(mode){
    case Mode::Ready:
      // Falling edge occurs when the handset is lifted --> 611 telephone
      if (buttonRecord.fallingEdge()) {
        Serial.println("Handset lifted");
        mode = Mode::Prompting; print_mode();
      }
      else if(buttonPlay.fallingEdge()) {
        //playAllRecordings();
        playLastRecording();
      }
      break;

    case Mode::Prompting:
      // Wait a second for users to put the handset to their ear
      wait(1500);
      // Play the greeting inviting them to record their message
      playWav1.play("greeting.wav");
      // Wait until the  message has finished playing
//      while (playWav1.isPlaying()) {
      while (!playWav1.isStopped()) {
        // Check whether the handset is replaced
        buttonRecord.update();
        buttonPlay.update();
        // Handset is replaced
        if(buttonRecord.risingEdge()) {
          playWav1.stop();
          mode = Mode::Ready; print_mode();
          return;
        }
        if(buttonPlay.fallingEdge()) {
          playWav1.stop();
          //playAllRecordings();
          playLastRecording();
          return;
        }

      }
      // Debug message
      Serial.println("Starting Recording");
      // Play the tone sound effect
      waveform1.begin(beep_volume, 440, WAVEFORM_SINE);
      wait(1250);
      waveform1.amplitude(0);

      // Start the recording function
      startRecording();
      //Timer
      startTime = millis();
      break;

    case Mode::Recording:
      // Handset is replaced
      //Reverse changes -Arthur
      //if(buttonRecord.risingEdge()){

#ifdef HANDHELD_CLOSES_ON_LIFT
//Timer

      if(buttonRecord.risingEdge() || millis() - startTime >=120000) {
        #else
        if (buttonRecord.fallingEdge()) {
          #endif

        // Debug log
        Serial.println("Stopping Recording");
        // Stop recording
        stopRecording();
        // Play audio tone to confirm recording has ended
        end_Beep();
      }
      else {
        continueRecording();
      }
      break;

    case Mode::Playing: // to make compiler happy
      break;

    case Mode::Initialising: // to make compiler happy
      break;
  }

  MTP.loop();  // This is mandatory to be placed in the loop code.
}

void setMTPdeviceChecks(bool nable)
{
  if (nable)
  {
    MTP.storage()->set_DeltaDeviceCheckTimeMS(MTPcheckInterval);
    Serial.print("En");
  }
  else
  {
    MTP.storage()->set_DeltaDeviceCheckTimeMS((uint32_t) -1);
    Serial.print("Dis");
  }
  Serial.println("abled MTP storage device checks");
}

#if defined(INSTRUMENT_SD_WRITE)
static uint32_t worstSDwrite, printNext;
#endif // defined(INSTRUMENT_SD_WRITE)

void startRecording() {
  setMTPdeviceChecks(false); // disable MTP device checks while recording
#if defined(INSTRUMENT_SD_WRITE)
  worstSDwrite = 0;
  printNext = 0;
#endif // defined(INSTRUMENT_SD_WRITE)
  // Find the first available file number
//  for (uint8_t i=0; i<9999; i++) { // BUGFIX uint8_t overflows if it reaches 255
  for (uint16_t i=0; i<9999; i++) {
    // Format the counter as a five-digit number with leading zeroes, followed by file extension
    snprintf(filename, 11, " %05d.wav", i);
    // Create if does not exist, do not open existing, write, sync after write
    if (!SD.exists(filename)) {
      break;
    }
  }
  frec = SD.open(filename, FILE_WRITE);
  Serial.println("Opened file !");
  if(frec) {
    Serial.print("Recording to ");
    Serial.println(filename);
    queue1.begin();
    mode = Mode::Recording; print_mode();
    recByteSaved = 0L;
  }
  else {
    Serial.println("Couldn't open file to record!");
  }
}

void continueRecording() {
#if defined(INSTRUMENT_SD_WRITE)
  uint32_t started = micros();

#endif // defined(INSTRUMENT_SD_WRITE)
#define NBLOX 16
  // Check if there is data in the queue
  if (queue1.available() >= NBLOX) {
    byte buffer[NBLOX*AUDIO_BLOCK_SAMPLES*sizeof(int16_t)];
    // Fetch 2 blocks from the audio library and copy
    // into a 512 byte buffer.  The Arduino SD library
    // is most efficient when full 512 byte sector size
    // writes are used.
    for (int i=0;i<NBLOX;i++)
    {
      memcpy(buffer+i*AUDIO_BLOCK_SAMPLES*sizeof(int16_t), queue1.readBuffer(), AUDIO_BLOCK_SAMPLES*sizeof(int16_t));
      queue1.freeBuffer();
    }
    // Write all 512 bytes to the SD card
    frec.write(buffer, sizeof buffer);
    recByteSaved += sizeof buffer;
  }

#if defined(INSTRUMENT_SD_WRITE)
  started = micros() - started;
  if (started > worstSDwrite)
    worstSDwrite = started;
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

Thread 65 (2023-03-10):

Blank files / No greeting playback

jhayen219, 2023-03-10:
Hey everyone. I am having an issue were I can hear the beeps in different stages of the code, but the greeting.wav is skipped. The code is also writing blank wav files to the SD card.

Hardware:
Teensy 4.1
Rev D Audio Shield

The audio jack from the handset has been tested using my computer, I can record and play back fine, so I know the handset is wired correctly.

The SD card is a 16 gb formatted in exFAT. That didn't work so I formatted to FAT32. That also didn't work. I can see the files written to the SD card, but they are blank .wav files. Since it is a 4.1 the SD card is mounted on the Teensy.

I read that someone had a solution to edit the greeting.wav to mono 16 bit PCM in audacity. I tried that, but I still do not get a greeting playback.

I would assume the pins are correct since the Teensy can at least write to the SD card.

Any assistance would be appreciated.

Thanks!

jhayen219, 2023-03-16:
To anyone having similar issues:

Realized the arduino audio shield headphone jack is output only. I wired my microphone to the microphone pins of the board and that seemed to solve that issue.

As far as the greeting playback goes, it was in 48k Hz and not 44.1k. Changed that in arduino and seemed to solve the issue

ranasats, 2023-03-22:
@jhayen219 Do you mind sharing your code that you're using for the 4.1 board? I am also not getting any sound out at all, no beep or anything.

Would love any assistance if you had anything to share.

Closed 2023-03-16.

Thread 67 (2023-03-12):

Greeting playback on phone noisy/robotic

critchio, 2023-03-12:
I have resolved all issues and everything seems to be working correctly except my greeting message is noisy/robotic. I recorded the WAV file in audacity using mono, 44100 hz, and 16-bit. I have tried adjusting volume down but it did not solve the issue. Thanks for any advice.

cadbury, 2023-03-16:
See my comment here: https://github.com/playfultechnology/audio-guestbook/issues/61#issuecomment-1472672451

Wucainclan, 2023-06-20:
Hey, experiencing a similar issue here with both the greeting, as well as the recordings coming back sounding robotic and either slow or fast. I'm using the original [code](https://github.com/playfultechnology/audio-guestbook/commit/6ea6f970a401c6c35241ee8f399e81da47a57c58) I referenced previous comments and tried those solutions and still can't seem to figure it out. I have also checked my connections by plugging the handset into my laptop and playing music through the speaker, etc.. I recorded my greeting message via audacity and exported at 44100hz, 16bit. I'm also using a teensy 4.0 and audio shield rev d2 with the sd card plugged into the audio shield.
Any help would be greatly appreciated!

cadbury, 2023-06-20:
In Audacity, choose effects, then amplify. Do -9db and see if it gets any better.

cadbury, 2023-06-21:
After lowering the volume, did it get any better? Or did it stay exactly the same?

Wucainclan, 2023-06-21:
> After lowering the volume, did it get any better? Or did it stay exactly the same?

It stayed exactly the same.

Wucainclan, 2023-06-26:
@cadbury Any other suggestions here? I've posted a new issue in case anyone else has any ideas, but no hits yet. Not sure where to go from here.

gever4ever, 2023-07-03:
Try switching to Normal blocksize (128), it solved the robotic sound to me.
I've yet to find the reason, might want to try the PJRC forums, they have a thread about the project,
https://forum.pjrc.com/threads/70553-Teensy-4-0-based-Audio-Guestbook

Wucainclan, 2023-07-03:
> Try switching to Normal blocksize (128), it solved the robotic sound to me.
> I've yet to find the reason, might want to try the PJRC forums, they have a thread about the project,
> https://forum.pjrc.com/threads/70553-Teensy-4-0-based-Audio-Guestbook

Did you just change that in the tools menu or did you go and adjust it in the code, as well?

gever4ever, 2023-07-04:
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

Just in the tools menu.

Wucainclan, 2023-07-04:
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

I tried that and am still experiencing it with the recordings. I managed to get the greeting to play fine but recordings are giving me trouble still.

gever4ever, 2023-07-04:
> I tried that and am still experiencing it with the recordings. I managed to get the greeting to play fine but recordings are giving me trouble still.

Could be a faulty / reversed mic wiring?
Also might want to try to play with the micGain. How do they sound on an external player?

Wucainclan, 2023-07-04:
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

I don't think it's reversed mic wiring. I checked the connections and swapped out the wires. I also played with the gain. I don't have a button for playback on the device so the recordings are always being played when I plug the SD card into my laptop. The only thing I can think of is it's an SD card thing since I'm using a Rev D2 audio shield (I changed the pin numbers on the code) or a faulty handset.

themilkman555, 2024-06-12:
I have a similar issue with the recordings being static/robotic while the greeting message is fine. Did you ever find a solution?

cadbury, 2024-06-12:
Adjusting the mic gain completely fixed it for me.

Depending on the phone, I needed different settings to fix the problem.

themilkman555, 2024-06-13:
> Adjusting the mic gain completely fixed it for me.
>
> Depending on the phone, I needed different settings to fix the problem.

Sorry, I'm pretty new to all this. Mic gain is something you change in the coding, right? Should I increase or decrease it and by how much do you think?

cadbury, 2024-06-13:
In the code. You probably need to lower it.

themilkman555, 2024-06-13:
You're referring to these lines here, right? I tried lowering from 15 to 5 and it didn't seem to make much of a difference?
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
It is a pretty old rotary phone, ~50s ish. Could the issue be with the mic there?
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

themilkman555, 2024-06-13:
Also just realized that in the hardware in the updated readme files it lists shielded microphone cable, which I did not use. Could that be affecting my sound quality? I just used the regular wiring I had on hand.

There is also a AOM5024 electret low noise microphone capsule listed on that hardware list. Could a better microphone possibly solve my issue?

cadbury, 2024-06-13:
I was able to get all mics work. Brand new phones, some from the 90s, 60s.

Try a lower gain 1, or even 0.5

themilkman555, 2024-06-13:
I’ve done trial and error with a range of gains, even setting it very low (gain=0) didn’t fix the static. I’m using a Western Electric model 500 rotary phone.

cadbury, 2024-06-13:
If you remove the SD card and play the file on a computer, does the audio still have problems?

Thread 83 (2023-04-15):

Unable to read the SD Card

Drightiger, 2023-04-15:
I'm not the first to have this problem and I wont be the last; previous threads on this are dead.

Firstly, thanks to Alistair and all the contributors on this project, you are providing a brilliant and frugal project for people to do whilst avoiding the absolute cash cow of the wedding industry (looking at you, At the Beep).

T4.0 w/ Audio shield D2. Code is running fine and I get the start up tone through the speaker and thereafter abruptly stopped at "Unable to read the SD card". Ive tried:
1. 2 different SD cards of different brands and a further on order, 64GB & 128GB (Both SDXC, could it require SDHC?). exFAT.
2. Resistance checked the connections between the boards and my solders - all good. [This is a good guide for diagnosing pin connection.](https://forum.pjrc.com/threads/70479-T4-0-audio-shield-SD-problem)
3. Tried the alternative defined pins that has apparently worked for someone else (10, 11, 13 instead of 10, 7, 14, I still don't understand why its the latter but whatever)

So help me god I've put hours into this, if someone helps me with this I'll pay it forward and delve into the YouTube comments for the many people in there struggling and help 1 person finish it off!

Drightiger, 2023-04-25:
Finally got this working, point 2 was my eureka moment:

1. If you are using Audioshield Rev D2 (or Rev D), you NEED to change the pins to 10 11 and 13 instead of 10 7 14. I suspect Alistair was using a Audioshield Rev C in his original code and on the video.
2. I re-soldered my 5V and 3.3v volt pins which were a bit of a mess but I thought they were passable, turns out they were not!
3. I changed to a SDHC 16GB card as opposed to a SDXC - this might not affect it but it could be potential issue.

If you hear the initial startup tone through the speaker but get the 'Unable to read SD card':

1. Check solders - I didn't want to believe this was my issue as I had experience soldering but it turns out it was. The SD card runs off the 3.3v pin, which is conveniently right next to a Ground pin - make sure they do not overlap (which I suspect was my problem).
2. Resistance check the 10 11 13 pins to make sure they're connected
3. Check your code that it references to 10 11 13 pins!

SlephenX, 2023-09-19:
I'm sorry, but why do we have to solder the 3.3V and the GRD pins? I thought they would be put together from attaching the board to the teensy 4.0 and then use the USB power?

Drightiger, 2023-09-19:
You should solder every header to the board, not just the ones that are being used

Closed 2023-05-01.

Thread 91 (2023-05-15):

Never stop recording

rogome, 2023-05-15:
I made my audio guestbook from an aliexpress "antique" phone. As shown in the video, my hanging button is backward. (Like the old office phone he checks). I've changed all the"button_recording.risingEdge()" for "button_recording.fallinEdge()" and vice versa. when I hang my phone, it beeps a couple of times, then It records for a second and starts again. It does the same even if you don't change the ringingEdge for fallingEdge. Does anyone know how to solve it? Is it supposed to work that way?
I'm adding a copy of the code version that I'm using.

[AudioGuestbook.txt](https://github.com/playfultechnology/audio-guestbook/files/11473988/AudioGuestbook.txt)

SwiFtEnRo, 2023-05-15:
@rogome Good morning,
Looking over your code here and where did you get this from? Your problem is in the "case Mode::Prompting:" stage.
I don't have too much time to look at this since I have to get to work so I'll reply later but where is your counter? Like how are you incrementing the messages and if the phone is replaced getting rid of that number in the count since its no longer relevant?
Here is what my "Prompting" stage code looks like:
`case Mode::Prompting:

             // Wait a second for users to put the handset to their ear.   RAM
             // Added to read hook pin to check if handset has been replaced before proceeding.  RAM
              
      x=0;   // Clear counter.
      while (x < 30)  {
        wait(50);   // Wait 50 mS.
        x=x+1;      // Increment counter
        Serial.println(x);  // Print counter value
        hookRead=digitalRead(HOOK_PIN);  // Check if handset replaced.
          if (hookRead==1)  {
            Serial.println("Handset Replaced Before Message");
            mode = Mode::Ready;  // Return to ready mode if hang up.
          return;
        }
      }

      // Play the greeting inviting them to record their message
      playRaw1.play("greeting.raw");    //  Changed from default (.wav) to (.raw) format.  Greeting MUST be recorded in .raw format.   RAM
      // Wait until the  message has finished playing
      while (playRaw1.isPlaying()) {

        // Check whether the handset is replaced
        buttonRecord.update();
        // Handset is replaced
        if(buttonRecord.risingEdge()) {
          playRaw1.stop();
          mode = Mode::Ready;
          return;

        }

      }
`

rogome, 2023-05-15:
@SwiFtEnRo I took the code from here: https://github.com/playfultechnology/audio-guestbook/blob/main/audio-guestbook.ino
It is probably a different version.
I know a little bit of coding but I'm mostly an enthusiasts.
I saw the version that u are using on a different forum, but didn't worked for me...

rogome, 2023-05-16:
@SwiFtEnRo the coda was updated, your version doesn't work for me.
In my version he is using
// Configure the input pins
  pinMode(HOOK_PIN, INPUT_PULLUP);
  pinMode(PLAYBACK_BUTTON_PIN, INPUT_PULLUP);
After what I've been reading the input_pullup is reading if the button is pressed or if it is not. If I change it for input_pulldown and it is not working better.
Any idea?

rogome, 2023-05-16:
Just in case someone reads this in the future.  If you have a flipped phone like mine and You are using the updated version of the code, You have to swap all the fallingEdge for risingEdge for the button record (and vice-versa).
pinMode(HOOK_PIN, INPUT_PULLUP);
pinMode(PLAYBACK_BUTTON_PIN, INPUT_PULLUP);
next step would be changing the pullup for pulldown
and then you have to change the hook connection from GND to 3.3V.
This is very important. If you do that, you'll have to add a resistor, otherwise, you will kill the teensy board.
This part depends on your phone hook button. Please double-check it.

Closed 2023-05-16.

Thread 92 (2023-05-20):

Unable to access the SD card

Jipsey-A, 2023-05-20:
Hi!
I'm fairly confident in my hardware installation - I've stumbled my way through the software side of things. I think I've done the new set-up correctly (although "Audio tweaks" does not appear for me).  My teensy 4.0 appears to have accepted the code, but the serial read says 'Unable to access SD card'. My SD card was empty, I loaded a Greeting.wav file recorded on Audacity saved as 16 bit, 44.1kHz. I put it into the teensy set-up and received the 'unable to access SD card'. When I put it back into my laptop I can now see a second file called mtpindex.dat
I wonder whether it's something to do with the way the SD card's formatted??

Grateful for your help!

Jipsey-A, 2023-05-21:
After reading other issues on here I purchased a new 'A1' SD card, I reformatted this to 'exFAT' and the serial monitor now shows:
19:54:02.605 -> Serial set up correctly
19:54:02.605 -> Audio block set to 128 samples
19:54:02.605 -> Mode switched to:  Initialising
But it doesn't do anything else...

Kenitilas, 2023-05-26:
I am not sure if you still have a SD Card problem. I usually use SD Memory Card Formatter to prepare my cards
[https://www.sdcard.org/downloads/formatter/](url)

Do you want the 128 sample blocks or is this an issue with the bigger blocks?
I had a ground loop in my wiring and thus couldn't hear or record anything

Jipsey-A, 2023-05-26:
Hi @Kenitilas
I got the SD card working but now (depending on which way I code falling and rising edge) I either find that the hook switch works in reverse, or that I get a false hang-up a moment into the greeting message. I think this is caused by an issue with my wiring the circuit board. Please could you share where / how you found the ground loop? I suspect this may be the problem for me too!
Thank you!

Kenitilas, 2023-05-26:
Hey
keep in mind that the switch of the handle button is multiple times in the code! I changed the code to the wrong setup on purpose, because this way it was way easier for me testing the phone by just tapping the handle, but maybe this is just my weird thing ;)
I found my ground loop by taking the multimeter and measuring all wires by its own. This may take some time but so I found a wrong-wired button. In my case I wired the ground level to an input pin of the teensy. You can also check the phone for a universal ground. Mine already had big ground trace on the back of the PCB I could use for all my GND connections.
Hope this helps!

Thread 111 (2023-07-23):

No sound in recordings

relishandpickles, 2023-07-23:
I've been messing around with this thing for months.

A lot of troubleshooting later, and everything seems to work but the recordings. Telephone beeps, plays the greeting, goes into the recording phase, lights flash on the device showing that it is recording, hang up the phone and it stops as it should.

The problem is that when I access the recordings, there is no sound. The files seem to contain data proportional to how long the recording was, but I don't hear anything. Audacity shows there is no waveforms in the recording.

I've reinstalled everything from the ground up over and over. No compiling errors. I've soldered over and over, checked all the connections, and cannot for the life of me figure out why the recordings have no sound.

Am I missing something? Any idea of why everything would work besides it capturing audio?

schneekluth, 2023-07-31:
Same here. I have checked wiring and soldering and my recordings only contain some kind of ticking noises.

schneekluth, 2023-08-01:
@relishandpickles Hey, I have just figured out that the microphone in the old telephone I am using is simply broken. Maybe you did everything right like me but the old hardware is the issue.

schaleroo, 2023-08-07:
Did you solve it? I have the same probem, even tried a new working microphone with no results

schneekluth, 2023-08-07:
I have indeed solved it an it was **not** the microphone. I had to break a second circuit directly on the pcb of the phone.

**Try the following:** Search a microphone with 3.5mm headphone jack (e.g. old PS4 headset). The position of the 3.5mm jack rings for thre microphone and ground have the same distance as the mic connectors on the audio shield. Place the jack's rings directly against the pins and try to record some audio. If this works your problem is not the microphone.

DianeM8739, 2023-08-27:
im still having this issue. maybe its my hardware connections? I also had to reverse the falling and risingedge because of the way my phone is setup. I hear the greeting fine but just empty recordings.

DianeM8739, 2023-08-27:
Maybe i messed up the code?

`/**
 * Audio Guestbook, Copyright (c) 2022 Playful Technology
 *
 * Tested using a Teensy 4.0 with Teensy Audio Shield, although should work
 * with minor modifications on other similar hardware
 *
 * When handset is lifted, a pre-recorded greeting message is played, followed by a tone.
 * Then, recording starts, and continues until the handset is replaced.
 * Playback button allows all messages currently saved on SD card through earpiece
 *
 * Files are saved on SD card as 44.1kHz, 16-bit, mono signed integer RAW audio format
 * --> changed this to WAV recording, DD4WH 2022_07_31
 * --> added MTP support, which enables copying WAV files from the SD card via the USB connection, DD4WH 2022_08_01
 *
 *
 * Frank DD4WH, August 1st 2022
 * for a DBP 611 telephone (closed contact when handheld is lifted) & with recording to WAV file
 * contact for switch button 0 is closed when handheld is lifted
 *
 * GNU GPL v3.0 license
 *
 */

#include <Bounce.h>
#include <Audio.h>
#include <Wire.h>
#include <SPI.h>
#include <SD.h>
#include <TimeLib.h>
#include <MTP_Teensy.h>
#include "play_sd_wav.h" // local copy with fixes

// DEFINES
// Define pins used by Teensy Audio Shield
#define SDCARD_CS_PIN    10
#define SDCARD_MOSI_PIN  7
#define SDCARD_SCK_PIN   14
// And those used for inputs
#define HOOK_PIN 0
#define PLAYBACK_BUTTON_PIN 1

#define noINSTRUMENT_SD_WRITE

// GLOBALS
// Audio initialisation code can be generated using the GUI interface at https://www.pjrc.com/teensy/gui/
// Inputs
AudioSynthWaveform          waveform1; // To create the "beep" sfx
AudioInputI2S               i2s2; // I2S input from microphone on audio shield
AudioPlaySdWavX              playWav1; // Play 44.1kHz 16-bit PCM greeting WAV file
AudioRecordQueue            queue1; // Creating an audio buffer in memory before saving to SD
AudioMixer4                 mixer; // Allows merging several inputs to same output
AudioOutputI2S              i2s1; // I2S interface to Speaker/Line Out on Audio shield
AudioConnection patchCord1(waveform1, 0, mixer, 0); // wave to mixer
AudioConnection patchCord3(playWav1, 0, mixer, 1); // wav file playback mixer
AudioConnection patchCord4(mixer, 0, i2s1, 0); // mixer output to speaker (L)
AudioConnection patchCord6(mixer, 0, i2s1, 1); // mixer output to speaker (R)
AudioConnection patchCord5(i2s2, 0, queue1, 0); // mic input to queue (L)
AudioControlSGTL5000      sgtl5000_1;

// Filename to save audio recording on SD card
char filename[15];
// The file object itself
File frec;

// Use long 40ms debounce time on both switches
Bounce buttonRecord = Bounce(HOOK_PIN, 40);
Bounce buttonPlay = Bounce(PLAYBACK_BUTTON_PIN, 40);

// Keep track of current state of the device
enum Mode {Initialising, Ready, Prompting, Recording, Playing};
Mode mode = Mode::Initialising;

float beep_volume = 0.04f; // not too loud :-)

uint32_t MTPcheckInterval; // default value of device check interval [ms]

// variables for writing to WAV file
unsigned long ChunkSize = 0L;
unsigned long Subchunk1Size = 16;
unsigned int AudioFormat = 1;
unsigned int numChannels = 1;
unsigned long sampleRate = 44100;
unsigned int bitsPerSample = 16;
unsigned long byteRate = sampleRate*numChannels*(bitsPerSample/8);// samplerate x channels x (bitspersample / 8)
unsigned int blockAlign = numChannels*bitsPerSample/8;
unsigned long Subchunk2Size = 0L;
unsigned long recByteSaved = 0L;
unsigned long NumSamples = 0L;
byte byte1, byte2, byte3, byte4;

void setup() {

  Serial.begin(9600);
  while (!Serial && millis() < 5000) {
    // wait for serial port to connect.
  }
  Serial.println("Serial set up correctly");
  Serial.printf("Audio block set to %d samples\n",AUDIO_BLOCK_SAMPLES);
  print_mode();
  // Configure the input pins
  pinMode(HOOK_PIN, INPUT_PULLUP);
  pinMode(PLAYBACK_BUTTON_PIN, INPUT_PULLUP);

  // Audio connections require memory, and the record queue
  // uses this memory to buffer incoming audio.
  AudioMemory(60);

  // Enable the audio shield, select input, and enable output
  sgtl5000_1.enable();
  // Define which input on the audio shield to use (AUDIO_INPUT_LINEIN / AUDIO_INPUT_MIC)
  sgtl5000_1.inputSelect(AUDIO_INPUT_MIC);
  //sgtl5000_1.adcHighPassFilterDisable(); //
  sgtl5000_1.volume(0.95);

  mixer.gain(0, 1.0f);
  mixer.gain(1, 1.0f);

  // Play a beep to indicate system is online
  waveform1.begin(beep_volume, 440, WAVEFORM_SINE);
  wait(1000);
  waveform1.amplitude(0);
  delay(1000);

  // Initialize the SD card
  SPI.setMOSI(SDCARD_MOSI_PIN);
  SPI.setSCK(SDCARD_SCK_PIN);
  if (!(SD.begin(SDCARD_CS_PIN)))
  {
    // stop here if no SD card, but print a message
    while (1) {
      Serial.println("Unable to access the SD card");
      delay(500);
    }
  }
    else Serial.println("SD card correctly initialized");

  // mandatory to begin the MTP session.
    MTP.begin();

  // Add SD Card
//    MTP.addFilesystem(SD, "SD Card");
    MTP.addFilesystem(SD, "Kais Audio guestbook"); // choose a nice name for the SD card volume to appear in your file explorer
    Serial.println("Added SD card via MTP");
    MTPcheckInterval = MTP.storage()->get_DeltaDeviceCheckTimeMS();

    // Value in dB
//  sgtl5000_1.micGain(15);
  sgtl5000_1.micGain(5); // much lower gain is required for the AOM5024 electret capsule

  // Synchronise the Time object used in the program code with the RTC time provider.
  // See https://github.com/PaulStoffregen/Time
  setSyncProvider(getTeensy3Time);

  // Define a callback that will assign the correct datetime for any file system operations
  // (i.e. saving a new audio recording onto the SD card)
  FsDateTime::setCallback(dateTime);

  mode = Mode::Ready; print_mode();
}

void loop() {
  // First, read the buttons
  buttonRecord.update();
  buttonPlay.update();

  switch(mode){
    case Mode::Ready:
      // Falling edge occurs when the handset is lifted --> 611 telephone
      if (buttonRecord.risingEdge()) {
        Serial.println("Handset lifted");
        mode = Mode::Prompting; print_mode();
      }
      else if(buttonPlay.fallingEdge()) {
        //playAllRecordings();
        playLastRecording();
      }
      break;

    case Mode::Prompting:
      // Wait a second for users to put the handset to their ear
      wait(1000);
      // Play the greeting inviting them to record their message
      playWav1.play("greeting.wav");
      // Wait until the  message has finished playing
//      while (playWav1.isPlaying()) {
      while (!playWav1.isStopped()) {
        // Check whether the handset is replaced
        buttonRecord.update();
        buttonPlay.update();
        // Handset is replaced
        if(buttonRecord.fallingEdge()) {
          playWav1.stop();
          mode = Mode::Ready; print_mode();
          return;
        }
        if(buttonPlay.risingEdge()) {
          playWav1.stop();
          //playAllRecordings();
          playLastRecording();
          return;
        }

      }
      // Debug message
      Serial.println("Starting Recording");
      // Play the tone sound effect
      waveform1.begin(beep_volume, 440, WAVEFORM_SINE);
      wait(1250);
      waveform1.amplitude(0);
      // Start the recording function
      startRecording();
      break;

    case Mode::Recording:
      // Handset is replaced
      if(buttonRecord.fallingEdge()){
        // Debug log
        Serial.println("Stopping Recording");
        // Stop recording
        stopRecording();
        // Play audio tone to confirm recording has ended
        end_Beep();
      }
      else {
        continueRecording();
      }
      break;

    case Mode::Playing: // to make compiler happy
      break;

    case Mode::Initialising: // to make compiler happy
      break;
  }

  MTP.loop();  // This is mandatory to be placed in the loop code.
}

void setMTPdeviceChecks(bool nable)
{
  if (nable)
  {
    MTP.storage()->set_DeltaDeviceCheckTimeMS(MTPcheckInterval);
    Serial.print("En");
  }
  else
  {
    MTP.storage()->set_DeltaDeviceCheckTimeMS((uint32_t) -1);
    Serial.print("Dis");
  }
  Serial.println("abled MTP storage device checks");
}

#if defined(INSTRUMENT_SD_WRITE)
static uint32_t worstSDwrite, printNext;
#endif // defined(INSTRUMENT_SD_WRITE)
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
BGOLDEN1994, 2023-11-16:
I had this same issue. I chased code, replaced wires, replace the mic, everything you can think of.
Turns out it was how the phone was designed.

When first building the phone, I found the microphone pins on the circuit board itself and soldered directly to those WITHOUT disconnecting the mic from the board, similar to how he does in the video. This was a mistake, since the microphone has some sort of transformer in parallel with the mic which throws off the teensy, probably by drawing lots of power from the mic output.

To fix this, I took a Dremel and cut all of the board traces that also ran to the handset mic. If I were to do this again, I would make sure to run a direct connection from the handset mic to the teensy by cutting and splicing directly to the handset mic wires.

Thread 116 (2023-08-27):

SD card is not connected or unusable :-(

DianeM8739, 2023-08-27:
Hi i need assistance. I tried using the serial monitor after the code was uploaded and I kept getting the error UNABLE TO ACCESS SD CARD. ran the SD test and got this error: SD card is not connected or unusable :-(

Card is already formatted. I used https://www.sdcard.org/downloads/formatter/sd-memory-card-formatter-for-windows-download/
I've used different SD cards and keep getting the same error

Am i missing something? How can i fix this?

DianeM8739, 2023-08-28:
Nevermind I got it!

bryandeagle, 2023-09-01:
@DianeM8739 Can you elaborate on what you had wrong? I'm experiencing a similar issue.

Vinestou, 2023-09-02:
Same here! Please let us know @DianeM8739

bryandeagle, 2023-09-03:
I solved my issue. I didn’t realize the ground pins on the audio shield are not connected to each other, and they all need to be connected to the teensy for the SD card to work

Vinestou, 2023-09-03:
> I solved my issue. I didn’t realize the ground pins on the audio shield are not connected to each other, and they all need to be connected to the teensy for the SD card to work

Thanks for you reply. Does that include the gnd from the mic? I have built the board without connecting it to the Phone. maby that is my problem (no GND connected).

Vinestou, 2023-09-03:
@bryandeagle Ok soldered everything and the SD can be found!

DianeM8739, 2023-09-03:
That was the same issue i had. Thanks. On Sep 3, 2023, at 4:48 PM, Vinestou ***@***.***> wrote:
@bryandeagle Ok soldered everything and the SD can be found!

—Reply to this email directly, view it on GitHub, or unsubscribe.You are receiving this because you were mentioned.Message ID: ***@***.***>

cp1797, 2023-10-07:
I have a Teensy 4.0 with Audio shield Rev D2 hooked up with soldered on headers. I've tried everything but the SD Card just doesn't detect. Keeps showing "Unable to access the SD card".

Going by [this comment](https://github.com/playfultechnology/audio-guestbook/issues/116#issuecomment-1703992567), I've checked with a multimeter the connection of the G pin between 5v and 3.3v and the GND pin and they are connected. CS is set to 10. I've also tried 7 through 14.

What am I doing wrong?? Would really appreciate the help.

jogiblade, 2023-11-22:
> I solved my issue. I didn’t realize the ground pins on the audio shield are not connected to each other, and they all need to be connected to the teensy for the SD card to work

Hello,
which Pins have you soldered? Can you please specify?

bryandeagle, 2023-11-22:
There are two ground pins on the audio shield. They both must be connected to the teensy to function.

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

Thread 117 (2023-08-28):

Newbie trying to make this work

PyrotekFX, 2023-08-28:
Hello, sorry if this is a really silly question, I'm trying to make this work and the MTP library keeps coming up as missing, is there a way to download a compiled library or can someone point me in the direction of a video which I can follow step by step to get this done? Thank you.

PyrotekFX, 2023-08-28:
Got the MTP working, everything seems to be working ok, all except I get a clicking in the audio when I'm listening to the recording and when I make my recording its there too. The SD card is a Sandisk Ultra so should be fast enough, dont know if I'm missing something. File of the audio has been uploaded to see if anyone has a fix. I tried doing the 256 sample thing and it just make the greeting super slow.

/**
 * Audio Guestbook, Copyright (c) 2022 Playful Technology
 *
 * Tested using a Teensy 4.0 with Teensy Audio Shield, although should work
 * with minor modifications on other similar hardware
 *
 * When handset is lifted, a pre-recorded greeting message is played, followed by a tone.
 * Then, recording starts, and continues until the handset is replaced.
 * Playback button allows all messages currently saved on SD card through earpiece
 *
 * Files are saved on SD card as 44.1kHz, 16-bit, mono signed integer RAW audio format
 * --> changed this to WAV recording, DD4WH 2022_07_31
 * --> added MTP support, which enables copying WAV files from the SD card via the USB connection, DD4WH 2022_08_01
 *
 *
 * Frank DD4WH, August 1st 2022
 * for a DBP 611 telephone (closed contact when handheld is lifted) & with recording to WAV file
 * contact for switch button 0 is closed when handheld is lifted
 *
 * GNU GPL v3.0 license
 *
 */

#include <Bounce.h>
#include <Audio.h>
#include <Wire.h>
#include <SPI.h>
#include <SD.h>
#include <TimeLib.h>
#include <MTP_Teensy.h>
#include "play_sd_wav.h" // local copy with fixes

// DEFINES
// Define pins used by Teensy Audio Shield
#define SDCARD_CS_PIN    10
#define SDCARD_MOSI_PIN  7
#define SDCARD_SCK_PIN   14
// And those used for inputs
#define HOOK_PIN 0
#define PLAYBACK_BUTTON_PIN 1

#define noINSTRUMENT_SD_WRITE

// GLOBALS
// Audio initialisation code can be generated using the GUI interface at https://www.pjrc.com/teensy/gui/
// Inputs
AudioSynthWaveform          waveform1; // To create the "beep" sfx
AudioInputI2S               i2s2; // I2S input from microphone on audio shield
AudioPlaySdWav              playWav1; // Play 44.1kHz 16-bit PCM greeting WAV file
AudioRecordQueue            queue1; // Creating an audio buffer in memory before saving to SD
AudioMixer4                 mixer; // Allows merging several inputs to same output
AudioOutputI2S              i2s1; // I2S interface to Speaker/Line Out on Audio shield
AudioConnection patchCord1(waveform1, 0, mixer, 0); // wave to mixer
AudioConnection patchCord3(playWav1, 0, mixer, 1); // wav file playback mixer
AudioConnection patchCord4(mixer, 0, i2s1, 0); // mixer output to speaker (L)
AudioConnection patchCord6(mixer, 0, i2s1, 1); // mixer output to speaker (R)
AudioConnection patchCord5(i2s2, 0, queue1, 0); // mic input to queue (L)
AudioControlSGTL5000      sgtl5000_1;

// Filename to save audio recording on SD card
char filename[15];
// The file object itself
File frec;

// Use long 40ms debounce time on both switches
Bounce buttonRecord = Bounce(HOOK_PIN, 40);
Bounce buttonPlay = Bounce(PLAYBACK_BUTTON_PIN, 40);

// Keep track of current state of the device
enum Mode {Initialising, Ready, Prompting, Recording, Playing};
Mode mode = Mode::Initialising;

float beep_volume = 0.04f; // not too loud :-)

uint32_t MTPcheckInterval; // default value of device check interval [ms]

// variables for writing to WAV file
unsigned long ChunkSize = 0L;
unsigned long Subchunk1Size = 16;
unsigned int AudioFormat = 1;
unsigned int numChannels = 1;
unsigned long sampleRate = 44100;
unsigned int bitsPerSample = 16;
unsigned long byteRate = sampleRate*numChannels*(bitsPerSample/8);// samplerate x channels x (bitspersample / 8)
unsigned int blockAlign = numChannels*bitsPerSample/8;
unsigned long Subchunk2Size = 0L;
unsigned long recByteSaved = 0L;
unsigned long NumSamples = 0L;
byte byte1, byte2, byte3, byte4;

void setup() {

  Serial.begin(9600);
  while (!Serial && millis() < 5000) {
    // wait for serial port to connect.
  }
  Serial.println("Serial set up correctly");
  Serial.printf("Audio block set to %d samples\n",AUDIO_BLOCK_SAMPLES);
  print_mode();
  // Configure the input pins
  pinMode(HOOK_PIN, INPUT_PULLUP);
  pinMode(PLAYBACK_BUTTON_PIN, INPUT_PULLUP);

  // Audio connections require memory, and the record queue
  // uses this memory to buffer incoming audio.
  AudioMemory(60);

  // Enable the audio shield, select input, and enable output
  sgtl5000_1.enable();
  // Define which input on the audio shield to use (AUDIO_INPUT_LINEIN / AUDIO_INPUT_MIC)
  sgtl5000_1.inputSelect(AUDIO_INPUT_MIC);
  //sgtl5000_1.adcHighPassFilterDisable(); //
  sgtl5000_1.volume(0.5);

  mixer.gain(0, 1.0f);
  mixer.gain(1, 1.0f);

  // Play a beep to indicate system is online
  waveform1.begin(beep_volume, 440, WAVEFORM_SINE);
  wait(1000);
  waveform1.amplitude(0);
  delay(1000);

  // Initialize the SD card
  SPI.setMOSI(SDCARD_MOSI_PIN);
  SPI.setSCK(SDCARD_SCK_PIN);
  if (!(SD.begin(SDCARD_CS_PIN)))
  {
    // stop here if no SD card, but print a message
    while (1) {
      Serial.println("Unable to access the SD card");
      delay(500);
    }
  }
    else Serial.println("SD card correctly initialized");

  // mandatory to begin the MTP session.
    MTP.begin();

  // Add SD Card
//    MTP.addFilesystem(SD, "SD Card");
    MTP.addFilesystem(SD, "Click Audio guestbook"); // choose a nice name for the SD card volume to appear in your file explorer
    Serial.println("Added SD card via MTP");
    MTPcheckInterval = MTP.storage()->get_DeltaDeviceCheckTimeMS();

    // Value in dB
//  sgtl5000_1.micGain(15);
  sgtl5000_1.micGain(40); // much lower gain is required for the AOM5024 electret capsule

  // Synchronise the Time object used in the program code with the RTC time provider.
  // See https://github.com/PaulStoffregen/Time
  setSyncProvider(getTeensy3Time);

  // Define a callback that will assign the correct datetime for any file system operations
  // (i.e. saving a new audio recording onto the SD card)
  FsDateTime::setCallback(dateTime);

  mode = Mode::Ready; print_mode();
}

void loop() {
  // First, read the buttons
  buttonRecord.update();
  buttonPlay.update();

  switch(mode){
    case Mode::Ready:
      // Falling edge occurs when the handset is lifted --> 611 telephone
      if (buttonRecord.risingEdge()) {
        Serial.println("Handset lifted");
        mode = Mode::Prompting; print_mode();
      }
      else if(buttonPlay.risingEdge()) {
        //playAllRecordings();
        playLastRecording();
      }
      break;
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
PyrotekFX, 2023-08-28:
2 white cables are joined to grey and purple are the hang up switch, yellow and black are connected to white and black are the mic, red and green are connected to speaker cable, I'll be attaching everything to a terminal block once it's ready to be closed up and put together. I didn't make a button for play all recordings because it's not something I want guests to be able to do.
![Uploading 20230829_083922.jpg…]()

PyrotekFX, 2023-08-28:
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

DianeM8739, 2023-08-28:
Omg! Are we working on the same phone??? Is that the Crosley pay phone???
Ok so for the rec i connected it to the R on the output side of audio shield and the other one right next to it G. Since i didn’t put in the audio Jack. I can send a pic in a few.

PyrotekFX, 2023-08-29:
I think that might be your problem, the coding might be written in a way to make it route through the 3.5mm port rather than the pin terminals, I just went to the electronics store and bought a mono 3.5mm cable to mono 3.5mm, cut it in half and spliced the cables together with the phones and it worked.

My phone is the knock off Crosley pay phone I found on Alibaba. In Australia the proper Crosley pay phone is astronomically expensive because no one has it here in stock.

DianeM8739, 2023-08-29:
Ahh ok. Yea i have an audio Jack wire but when i connected it - it wasn’t working. But then i also thought why should it be a recording issue with it since it’s connected to the receiver anyway and not the mic?? It could be my code so I’ll try adjusting the volume to what you recommended. But i can hear the greeting on my sd card great wired that way. The recording is the only issue for me.

PyrotekFX, 2023-08-29:
Yep I was the same, greeting came out super loud and clear, the recordings were barely audible, I only worked out it was a volume issue when I yelled at the phone out of frustration and it had the tiniest noise on the PC.

DianeM8739, 2023-08-29:
I’ll try that tonight when i work on it. Thanks!On Aug 28, 2023, at 9:06 PM, PyrotekFX ***@***.***> wrote:
Yep I was the same, greeting came out super loud and clear, the recordings were barely audible, I only worked out it was a volume issue when I yelled at the phone out of frustration and it had the tiniest noise on the PC.

—Reply to this email directly, view it on GitHub, or unsubscribe.You are receiving this because you commented.Message ID: ***@***.***>

PyrotekFX, 2023-08-29:
Not a problem, hope it works, did you work out the ticking issue though?

DianeM8739, 2023-08-29:
I got it!!! so i updated to what you recommended!! ok so i didnt need an audio jack. I connected (from the phone) REC - to LINE OUT L (audio shield) and + REC (phone) to LINE OUT G on the audio shield. no ticking sound!

PyrotekFX, 2023-08-30:
Got rid of the ticking noise too, Thank you for your help, hope all goes well with your jobs.

DianeM8739, 2023-08-30:
Thank you too!!!!On Aug 30, 2023, at 2:32 AM, PyrotekFX ***@***.***> wrote:
Got rid of the ticking noise too, Thank you for your help, hope all goes well with your jobs.

—Reply to this email directly, view it on GitHub, or unsubscribe.You are receiving this because you commented.Message ID: ***@***.***>

cp1797, 2023-10-07:
I have a Teensy 4.0 with Audio shield Rev D2 hooked up with soldered on headers. I've tried everything but the SD Card just doesn't detect. Keeps showing "Unable to access the SD card".

Going by [this comment](https://github.com/playfultechnology/audio-guestbook/issues/116#issuecomment-1703992567), I've checked with a multimeter the connection of the G pin between 5v and 3.3v and the GND pin and they are connected. CS is set to 10. I've also tried 7 through 14.

What am I doing wrong?? Would really appreciate the help.

DianeM8739, 2023-10-08:
So my issue was that i didn’t actually solder the pins together because i wanted to see if it works first. Once i soldered the pins to the audio shield it was able to recognize the sd card. Also make sure you reformat the sd card. On Oct 7, 2023, at 2:41 AM, Craig Pinto ***@***.***> wrote:
I have a Teensy 4.0 with Audio shield Rev D2 hooked up with soldered on headers. I've tried everything but the SD Card just doesn't detect. Keeps showing "Unable to access the SD card".
Going by this comment, I've checked with a multimeter the connection of the G pin between 5v and 3.3v and the GND pin and they are connected. CS is set to 10. I've also tried 7 through 14.
What am I doing wrong?? Would really appreciate the help.

—Reply to this email directly, view it on GitHub, or unsubscribe.You are receiving this because you commented.Message ID: ***@***.***>

Closed 2023-10-10.

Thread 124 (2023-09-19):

No tone, or message. Recording but no sound recorded. Already looked through previous 'Issues' threads

256colorstoo, 2023-09-19:
Hi y'all! Just want to say that I really love how much help these threads have provided.

I am running through:
-Teensy 4.0
-Rev D2

I'm having some trouble with audio that I know others have had. From the title, I am not hearing any sound from the speaker and nothing is recording from my microphone. There are files that have no sound, I increased the volume and still no hints of any audio. There is a file and is the length that I have the telephone off the plunger. So here's what I tried :

-Using the serial monitor, I can see that the code is working. When I push down the plunger I can see the code react to it.
I know that the speaker works because I plugged in my cellphone (Playing a youtube video) through the 3.5mm jack and I could hear the sound coming through the speaker.

-I have had troubles with a "unable to access SD card" until I resoldered some pins. And Then I was able to get it to work. My solders look good now and everything is connected properly. (For those who are stuck there. make sure that all the numbered pins of your teensy are connected to all numbered pins to your board)

-I've followed the wires from the speaker/microphone onto the phone board. I have screw on terminals, so i just hooked the bare wire around and tightened it. (Again I can prove this works because of the audio through the video playing off my cellphone).

-I've used pin head connectors to connect the two boards. Then soldered the microphone to the board. And I've stripped wire to fit into the female connector pins. So everything is connected pretty well.

-my greeting is labeled "greeting.wav". at 44.1 khz and 16-bit. The "empty" audio files come back as .wav files. So ideally everything looks to be working fine.

In tools I have selected:
Board=teensy 4.0
usb type=Serial + MTP Disk (Experimental)
CPU speed=150 mhz
Optimize=Faster
Audio Tweaks=Bigger blocks (256 Samples)

My working theory:

I think it has to deal with the code. I did have to back track a lot to add in the "local.board" and other files. I'm thinking theres this disconnect from the code to the board, since the code is recording but not using the microphone as the input. I'm very much at a loss and I'm continuing to look into the code to find anything that may help me identify if there is a missing input or maybe I didnt read an instruction and didn't change something.

pls halp. Gracias and any advice would be very appreciated.

brian-v8, 2023-09-21:
I am having this exact same issue. I need the phone by this Saturday so any help would be appreciated! I will update if I find a solution.

brian-v8, 2023-09-22:
After much troubleshooting, I tried this with another teensy processor with pre-soldered pins and everything works as it should. I am not sure if this was due to a faulty soldering job on my part or if the processor was bad. Double-check your solder joints and wiring.

256colorstoo, 2023-09-30:
Thank you @brian-v8 !!! So for anyone reading this he was right. I thought I had every pin connected but, due to some awkward placing of female connector boards, I had not connected every pin to the two boards. basically i had gaps and some of the points on the bottom board (9,17) weren't connected to the top board.

In the future, CONNECT EVERY NUMBER FROM THE BOTTOM BOARD TO THE TOP BOARD. Now I have this awful jerry rigged mess that I may just buy the presoldered board for and star all over again.  Good news is that it works now. I have the wires from the phone (both receiver and speaker) connected straight to the board. Just make sure to find the plunger on the phone terminal, That need be connected still.

Beyond that, I've just got to re-record my message and work out the volume issues ( which that isn't too much trouble) and just find a way to pack it all in. Either in the phone itself or an outside box like in the OG video. Thanks so much for the help, I now know way more about electronics than I did when I initially started and fundamentally look at problems differently. I've recently bought two (new to me) phones and I'm going to replicate this all over again... This time with KNOWLEDGE!!! This whole group has been a big help!!

Closed 2023-09-30.

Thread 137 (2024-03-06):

Power issue?? Works fine only when plugged into computer!

Handerson91, 2024-03-06:
Hi all, I'm really hoping someone can help me! I'm so close to getting this thing working!

I've worked through a bunch of errors and issues thanks to all the other comments and now when I have the phone pulled apart and connected by USB to the computer, it works great! I managed to edit the code to not only play back the most recent recording but to be able to skip back through the 5 most recent recordings (see my comment on #62 for details).

However, as soon as I unplug from the CPU and try to use any other power source, it doesn't work.  The red LED flashes on and off slowly and nothing works.  At first I thought it was the battery pack - I've tried to attach a 3xAA battery pack to the VIN and G ports  and upon unplugging and testing with batteries, it wouldn't work (the LED flashing is dimmer than when it's plugged into the CPU).  Next I tried to plug it into a USB battery pack and while the LED flashing was the same as when plugged in, there was still no function!

If anyone has any suggestions or can tell me where I'm going wrong, I'd be SO appreciative! I'm just under a month out of the wedding and I really want to be able to have it working as a self-contained unit and not plugged into a laptop! I don't trust drunken guests that much!

Thanks in advance

MonkeyHanger95, 2024-09-22:
Hi Handerson91, where you able figure this one out? I'm in the same situation as you were, works fine however I want contain the board and power supply in an external box.

What did you go with in the end for the batter supply? I was planning on using 3xAA batteries, I have a 4 slot aa supply but think the voltage is too high for what the VIn can receive.

Any help would be appreciated. Thanks.

Handerson91, 2024-09-23:
It's been a few months but someone replied to one of my comments and helped me fix the issue.  I can't find the thread now so maybe it's been deleted.  Not sure if you're doing what I was doing but I thought the button on the Teensy was a restart button but it's a full reset.  From memory, you have to configure the code onto the teensy plugged into the computer and once it's done, immediately unplug. Don't test it by picking up the receiver or it holds it on a loop waiting for input from the computer even after you disconnect it.  If you press the button on the teensy, it wipes the code stored on it and so there's nothing for it to run.  Mine worked fine after that.

Pretty sure I went with a 3xAA battery pack.  I can't access it to check at the moment though.  I was able to get it all contained within the body of the phone so it was completely portable. Good luck!

MonkeyHanger95, 2024-09-26:
That's exactly what I was doing... I didn't realise it was being wiped and thought that was just a reset button as you said.

I've gone for 3xAA batteries and it works fine (the connection to the 5v header is currently loose & doing my head in but i'll fix that).

Thanks mate, appreciate the help

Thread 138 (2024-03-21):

Greeting message loops infinitely.

AnxiemeMusic, 2024-03-21:
I managed to get my phone working and recording great. My issue came when I added in my greeting message. When I pick up the phone now it just plays back the message over and over. Almost like the loop does not realize it has been satisfied.

`/**
 * Audio Guestbook, Copyright (c) 2022 Playful Technology
 *
 * Tested using a Teensy 4.0 with Teensy Audio Shield, although should work
 * with minor modifications on other similar hardware
 *
 * When handset is lifted, a pre-recorded greeting message is played, followed by a tone.
 * Then, recording starts, and continues until the handset is replaced.
 * Playback button allows all messages currently saved on SD card through earpiece
 *
 * Files are saved on SD card as 44.1kHz, 16-bit, mono signed integer RAW audio format
 * --> changed this to WAV recording, DD4WH 2022_07_31
 * --> added MTP support, which enables copying WAV files from the SD card via the USB connection, DD4WH 2022_08_01
 *
 *
 * Frank DD4WH, August 1st 2022
 * for a DBP 611 telephone (closed contact when handheld is lifted) & with recording to WAV file
 * contact for switch button 0 is closed when handheld is lifted
 *
 * GNU GPL v3.0 license
 *
 */

#include <Bounce.h>
#include <Audio.h>
#include <Wire.h>
#include <SPI.h>
#include <SD.h>
#include <TimeLib.h>
#include <MTP_Teensy.h>
#include "play_sd_wav.h" // local copy with fixes

// DEFINES
// Define pins used by Teensy Audio Shield
#define SDCARD_CS_PIN    10
#define SDCARD_MOSI_PIN  7
#define SDCARD_SCK_PIN   14
// And those used for inputs
#define HOOK_PIN 0
#define PLAYBACK_BUTTON_PIN 1

#define noINSTRUMENT_SD_WRITE

// GLOBALS
// Audio initialisation code can be generated using the GUI interface at https://www.pjrc.com/teensy/gui/
// Inputs
AudioSynthWaveform          waveform1; // To create the "beep" sfx
AudioInputI2S               i2s2; // I2S input from microphone on audio shield
AudioPlaySdWavX              playWav1; // Play 44.1kHz 16-bit PCM greeting WAV file
AudioRecordQueue            queue1; // Creating an audio buffer in memory before saving to SD
AudioMixer4                 mixer; // Allows merging several inputs to same output
AudioOutputI2S              i2s1; // I2S interface to Speaker/Line Out on Audio shield
AudioConnection patchCord1(waveform1, 0, mixer, 0); // wave to mixer
AudioConnection patchCord3(playWav1, 0, mixer, 1); // wav file playback mixer
AudioConnection patchCord4(mixer, 0, i2s1, 0); // mixer output to speaker (L)
AudioConnection patchCord6(mixer, 0, i2s1, 1); // mixer output to speaker (R)
AudioConnection patchCord5(i2s2, 0, queue1, 0); // mic input to queue (L)
AudioControlSGTL5000      sgtl5000_1;

// Filename to save audio recording on SD card
char filename[15];
// The file object itself
File frec;

// Use long 40ms debounce time on both switches
Bounce buttonRecord = Bounce(HOOK_PIN, 40);
Bounce buttonPlay = Bounce(PLAYBACK_BUTTON_PIN, 40);

// Keep track of current state of the device
enum Mode {Initialising, Ready, Prompting, Recording, Playing};
Mode mode = Mode::Initialising;

float beep_volume = 0.04f; // not too loud :-)

uint32_t MTPcheckInterval; // default value of device check interval [ms]

// variables for writing to WAV file
unsigned long ChunkSize = 0L;
unsigned long Subchunk1Size = 16;
unsigned int AudioFormat = 1;
unsigned int numChannels = 1;
unsigned long sampleRate = 44100;
unsigned int bitsPerSample = 16;
unsigned long byteRate = sampleRate*numChannels*(bitsPerSample/8);// samplerate x channels x (bitspersample / 8)
unsigned int blockAlign = numChannels*bitsPerSample/8;
unsigned long Subchunk2Size = 0L;
unsigned long recByteSaved = 0L;
unsigned long NumSamples = 0L;
byte byte1, byte2, byte3, byte4;

void setup() {

  Serial.begin(9600);
  while (!Serial && millis() < 5000) {
    // wait for serial port to connect.
  }
  Serial.println("Serial set up correctly");
  Serial.printf("Audio block set to %d samples\n",AUDIO_BLOCK_SAMPLES);
  print_mode();
  // Configure the input pins
  pinMode(HOOK_PIN, INPUT_PULLUP);
  pinMode(PLAYBACK_BUTTON_PIN, INPUT_PULLUP);

  // Audio connections require memory, and the record queue
  // uses this memory to buffer incoming audio.
  AudioMemory(60);

  // Enable the audio shield, select input, and enable output
  sgtl5000_1.enable();
  // Define which input on the audio shield to use (AUDIO_INPUT_LINEIN / AUDIO_INPUT_MIC)
  sgtl5000_1.inputSelect(AUDIO_INPUT_MIC);
  //sgtl5000_1.adcHighPassFilterDisable(); //
  sgtl5000_1.volume(0.95);

  mixer.gain(0, 1.0f);
  mixer.gain(1, 1.0f);

  // Play a beep to indicate system is online
  waveform1.begin(beep_volume, 440, WAVEFORM_SINE);
  wait(1000);
  waveform1.amplitude(0);
  delay(1000);

  // Initialize the SD card
  SPI.setMOSI(SDCARD_MOSI_PIN);
  SPI.setSCK(SDCARD_SCK_PIN);
  if (!(SD.begin(SDCARD_CS_PIN)))
  {
    // stop here if no SD card, but print a message
    while (1) {
      Serial.println("Unable to access the SD card");
      delay(500);
    }
  }
    else Serial.println("SD card correctly initialized");

  // mandatory to begin the MTP session.
    MTP.begin();

  // Add SD Card
//    MTP.addFilesystem(SD, "SD Card");
    MTP.addFilesystem(SD, "Derrick & Lindsay's Audio guestbook"); // choose a nice name for the SD card volume to appear in your file explorer
    Serial.println("Added SD card via MTP");
    MTPcheckInterval = MTP.storage()->get_DeltaDeviceCheckTimeMS();

    // Value in dB
//  sgtl5000_1.micGain(15);
  sgtl5000_1.micGain(10); // much lower gain is required for the AOM5024 electret capsule

  // Synchronise the Time object used in the program code with the RTC time provider.
  // See https://github.com/PaulStoffregen/Time
  setSyncProvider(getTeensy3Time);

  // Define a callback that will assign the correct datetime for any file system operations
  // (i.e. saving a new audio recording onto the SD card)
  FsDateTime::setCallback(dateTime);

  mode = Mode::Ready; print_mode();
}

void loop() {
  // First, read the buttons
  buttonRecord.update();
  buttonPlay.update();

  switch(mode){
    case Mode::Ready:
      // Falling edge occurs when the handset is lifted --> 611 telephone
      if (buttonRecord.fallingEdge()) {
        Serial.println("Handset lifted");
        mode = Mode::Prompting; print_mode();
      }
      else if(buttonPlay.fallingEdge()) {
        //playAllRecordings();
        playLastRecording();
      }
      break;

    case Mode::Prompting:
      // Wait a second for users to put the handset to their ear
      wait(1000);
      // Play the greeting inviting them to record their message
      playWav1.play("greeting.wav");
      // Wait until the  message has finished playing
//      while (playWav1.isPlaying()) {
      while (!playWav1.isStopped()) {
        // Check whether the handset is replaced
        buttonRecord.update();
        buttonPlay.update();
        // Handset is replaced
        if(buttonRecord.risingEdge()) {
          playWav1.stop();
          mode = Mode::Ready; print_mode();
          return;
        }
        if(buttonPlay.fallingEdge()) {
          playWav1.stop();
          //playAllRecordings();
          playLastRecording();
          return;
        }

      }
      // Debug message
      Serial.println("Starting Recording");
      // Play the tone sound effect
      waveform1.begin(beep_volume, 440, WAVEFORM_SINE);
      wait(1250);
      waveform1.amplitude(0);
      // Start the recording function
      startRecording();
      break;

    case Mode::Recording:
      // Handset is replaced
      if(buttonRecord.risingEdge()){
        // Debug log
        Serial.println("Stopping Recording");
        // Stop recording
        stopRecording();
        // Play audio tone to confirm recording has ended
        end_Beep();
      }
      else {
        continueRecording();
      }
      break;

    case Mode::Playing: // to make compiler happy
      break;

    case Mode::Initialising: // to make compiler happy
      break;
  }

  MTP.loop();  // This is mandatory to be placed in the loop code.
}

void setMTPdeviceChecks(bool nable)
{
  if (nable)
  {
    MTP.storage()->set_DeltaDeviceCheckTimeMS(MTPcheckInterval);
    Serial.print("En");
  }
  else
  {
    MTP.storage()->set_DeltaDeviceCheckTimeMS((uint32_t) -1);
    Serial.print("Dis");
  }
  Serial.println("abled MTP storage device checks");
}

#if defined(INSTRUMENT_SD_WRITE)
static uint32_t worstSDwrite, printNext;
#endif // defined(INSTRUMENT_SD_WRITE)

void startRecording() {
  setMTPdeviceChecks(false); // disable MTP device checks while recording
#if defined(INSTRUMENT_SD_WRITE)
  worstSDwrite = 0;
  printNext = 0;
#endif // defined(INSTRUMENT_SD_WRITE)
  // Find the first available file number
//  for (uint8_t i=0; i<9999; i++) { // BUGFIX uint8_t overflows if it reaches 255
  for (uint16_t i=0; i<9999; i++) {
    // Format the counter as a five-digit number with leading zeroes, followed by file extension
    snprintf(filename, 11, " %05d.wav", i);
    // Create if does not exist, do not open existing, write, sync after write
    if (!SD.exists(filename)) {
      break;
    }
  }
  frec = SD.open(filename, FILE_WRITE);
  Serial.println("Opened file !");
  if(frec) {
    Serial.print("Recording to ");
    Serial.println(filename);
    queue1.begin();
    mode = Mode::Recording; print_mode();
    recByteSaved = 0L;
  }
  else {
    Serial.println("Couldn't open file to record!");
  }
}

void continueRecording() {
#if defined(INSTRUMENT_SD_WRITE)
  uint32_t started = micros();
#endif // defined(INSTRUMENT_SD_WRITE)
#define NBLOX 16
  // Check if there is data in the queue
  if (queue1.available() >= NBLOX) {
    byte buffer[NBLOX*AUDIO_BLOCK_SAMPLES*sizeof(int16_t)];
    // Fetch 2 blocks from the audio library and copy
    // into a 512 byte buffer.  The Arduino SD library
    // is most efficient when full 512 byte sector size
    // writes are used.
    for (int i=0;i<NBLOX;i++)
    {
      memcpy(buffer+i*AUDIO_BLOCK_SAMPLES*sizeof(int16_t), queue1.readBuffer(), AUDIO_BLOCK_SAMPLES*sizeof(int16_t));
      queue1.freeBuffer();
    }
    // Write all 512 bytes to the SD card
    frec.write(buffer, sizeof buffer);
    recByteSaved += sizeof buffer;
  }

#if defined(INSTRUMENT_SD_WRITE)
  started = micros() - started;
  if (started > worstSDwrite)
    worstSDwrite = started;

  if (millis() >= printNext)
  {
    Serial.printf("Worst write took %luus\n",worstSDwrite);
    worstSDwrite = 0;
    printNext = millis()+250;
  }
#endif // defined(INSTRUMENT_SD_WRITE)
}

void stopRecording() {
  // Stop adding any new data to the queue
  queue1.end();
  // Flush all existing remaining data from the queue
  while (queue1.available() > 0) {
    // Save to open file
    frec.write((byte*)queue1.readBuffer(), AUDIO_BLOCK_SAMPLES*sizeof(int16_t));
    queue1.freeBuffer();
    recByteSaved += AUDIO_BLOCK_SAMPLES*sizeof(int16_t);
  }
  writeOutHeader();
  // Close the file
  frec.close();
  Serial.println("Closed file");
  mode = Mode::Ready; print_mode();
  setMTPdeviceChecks(true); // enable MTP device checks, recording is finished
}

void playAllRecordings() {
  // Recording files are saved in the root directory
  File dir = SD.open("/");
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
AnxiemeMusic, 2024-04-04:
bump

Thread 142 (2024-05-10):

Not detecting hook

256colorstoo, 2024-05-10:
So this is my second attempt at the guestbook. The first time used a vintage plunger phone. Now I'm using a phone that is connected to a board and doesn't have the usual connections.

I found where the plunger activated on the board and checked with my multimeter that it makes some difference in current when I press down on the plunger. Now before it would go from 1 to 0 value on the older phone. Now it goes 1 to .452 or so. It isn't a full disconnect. I'm wondering if there's a way to change the value on the "hookup" in the programming to maybe put in the more accurate value.

I checked serial monitor and it looks like my board is ready and set just no reaction when I press down on the plunger. I had some trouble finding the port to my teensy but I think I found it.

I can hear the initial beep from the speaker of the phone when I plug in the teensy to my computer but now there's no greeting after the beep (I have the greeting from the last phone that is already formatted correctly). Then pressing the plunger does nothing and I don't get any recordings.

I feel like I missed a step and am almost willing to completely wipe my computer of any Arduino/teensy software and just redo the whole thing. I don't know what steps I'm missing or what's going on. (I don't know if I should format my ad card or format the teensy board? This is all a bit much and I thought I could speed through it because I already did the last one.)

I know this ask is big and scatterbrained but any help would be very much appreciated. The first one ended up working out really well and was able to get it ready in time for my cousin's wedding. I'm hoping to get this second one off the ground for another party. Thanks in advance.

256colorstoo, 2024-05-11:
It was the wiring in plunger. I just had to switch the wires at the plunger connection.

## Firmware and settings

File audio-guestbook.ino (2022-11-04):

/**
 * Audio Guestbook, Copyright (c) 2022 Playful Technology
 * 
 * Tested using a Teensy 4.0 with Teensy Audio Shield, although should work 
 * with minor modifications on other similar hardware
 * 
 * When handset is lifted, a pre-recorded greeting message is played, followed by a tone.
 * Then, recording starts, and continues until the handset is replaced.
 * Playback button allows all messages currently saved on SD card through earpiece 
 * 
 * Files are saved on SD card as 44.1kHz, 16-bit, mono signed integer RAW audio format 
 * --> changed this to WAV recording, DD4WH 2022_07_31
 * --> added MTP support, which enables copying WAV files from the SD card via the USB connection, DD4WH 2022_08_01
 * 
 * 
 * Frank DD4WH, August 1st 2022 
 * for a DBP 611 telephone (closed contact when handheld is lifted) & with recording to WAV file
 * contact for switch button 0 is closed when handheld is lifted
 * 
 * GNU GPL v3.0 license
 * 
 */

#include <Bounce.h>
#include <Audio.h>
#include <Wire.h>
#include <SPI.h>
#include <SD.h>
#include <TimeLib.h>
#include <MTP_Teensy.h>
#include "play_sd_wav.h" // local copy with fixes

// DEFINES
// Define pins used by Teensy Audio Shield
#define SDCARD_CS_PIN    10
#define SDCARD_MOSI_PIN  7
#define SDCARD_SCK_PIN   14
// And those used for inputs
#define HOOK_PIN 0
#define PLAYBACK_BUTTON_PIN 1

#define noINSTRUMENT_SD_WRITE

// GLOBALS
// Audio initialisation code can be generated using the GUI interface at https://www.pjrc.com/teensy/gui/
// Inputs
AudioSynthWaveform          waveform1; // To create the "beep" sfx
AudioInputI2S               i2s2; // I2S input from microphone on audio shield
AudioPlaySdWavX              playWav1; // Play 44.1kHz 16-bit PCM greeting WAV file
AudioRecordQueue            queue1; // Creating an audio buffer in memory before saving to SD
AudioMixer4                 mixer; // Allows merging several inputs to same output
AudioOutputI2S              i2s1; // I2S interface to Speaker/Line Out on Audio shield
AudioConnection patchCord1(waveform1, 0, mixer, 0); // wave to mixer 
AudioConnection patchCord3(playWav1, 0, mixer, 1); // wav file playback mixer
AudioConnection patchCord4(mixer, 0, i2s1, 0); // mixer output to speaker (L)
AudioConnection patchCord6(mixer, 0, i2s1, 1); // mixer output to speaker (R)
AudioConnection patchCord5(i2s2, 0, queue1, 0); // mic input to queue (L)
AudioControlSGTL5000      sgtl5000_1;

// Filename to save audio recording on SD card
char filename[15];
// The file object itself
File frec;

// Use long 40ms debounce time on both switches
Bounce buttonRecord = Bounce(HOOK_PIN, 40);
Bounce buttonPlay = Bounce(PLAYBACK_BUTTON_PIN, 40);

// Keep track of current state of the device
enum Mode {Initialising, Ready, Prompting, Recording, Playing};
Mode mode = Mode::Initialising;

float beep_volume = 0.04f; // not too loud :-)

uint32_t MTPcheckInterval; // default value of device check interval [ms]

// variables for writing to WAV file
unsigned long ChunkSize = 0L;
unsigned long Subchunk1Size = 16;
unsigned int AudioFormat = 1;
unsigned int numChannels = 1;
unsigned long sampleRate = 44100;
unsigned int bitsPerSample = 16;
unsigned long byteRate = sampleRate*numChannels*(bitsPerSample/8);// samplerate x channels x (bitspersample / 8)
unsigned int blockAlign = numChannels*bitsPerSample/8;
unsigned long Subchunk2Size = 0L;
unsigned long recByteSaved = 0L;
unsigned long NumSamples = 0L;
byte byte1, byte2, byte3, byte4;


void setup() {

  Serial.begin(9600);
  while (!Serial && millis() < 5000) {
    // wait for serial port to connect.
  }
  Serial.println("Serial set up correctly");
  Serial.printf("Audio block set to %d samples\n",AUDIO_BLOCK_SAMPLES);
  print_mode();
  // Configure the input pins
  pinMode(HOOK_PIN, INPUT_PULLUP);
  pinMode(PLAYBACK_BUTTON_PIN, INPUT_PULLUP);

  // Audio connections require memory, and the record queue
  // uses this memory to buffer incoming audio.
  AudioMemory(60);

  // Enable the audio shield, select input, and enable output
  sgtl5000_1.enable();
  // Define which input on the audio shield to use (AUDIO_INPUT_LINEIN / AUDIO_INPUT_MIC)
  sgtl5000_1.inputSelect(AUDIO_INPUT_MIC);
  //sgtl5000_1.adcHighPassFilterDisable(); //
  sgtl5000_1.volume(0.95);

  mixer.gain(0, 1.0f);
  mixer.gain(1, 1.0f);

  // Play a beep to indicate system is online
  waveform1.begin(beep_volume, 440, WAVEFORM_SINE);
  wait(1000);
  waveform1.amplitude(0);
  delay(1000);

  // Initialize the SD card
  SPI.setMOSI(SDCARD_MOSI_PIN);
  SPI.setSCK(SDCARD_SCK_PIN);
  if (!(SD.begin(SDCARD_CS_PIN))) 
  {
    // stop here if no SD card, but print a message
    while (1) {
      Serial.println("Unable to access the SD card");
      delay(500);
    }
  }
    else Serial.println("SD card correctly initialized");


  // mandatory to begin the MTP session.
    MTP.begin();

  // Add SD Card
//    MTP.addFilesystem(SD, "SD Card");
    MTP.addFilesystem(SD, "Kais Audio guestbook"); // choose a nice name for the SD card volume to appear in your file explorer
    Serial.println("Added SD card via MTP");
    MTPcheckInterval = MTP.storage()->get_DeltaDeviceCheckTimeMS();
    
    // Value in dB
//  sgtl5000_1.micGain(15);
  sgtl5000_1.micGain(5); // much lower gain is required for the AOM5024 electret capsule

  // Synchronise the Time object used in the program code with the RTC time provider.
  // See https://github.com/PaulStoffregen/Time
  setSyncProvider(getTeensy3Time);
  
  // Define a callback that will assign the correct datetime for any file system operations
  // (i.e. saving a new audio recording onto the SD card)
  FsDateTime::setCallback(dateTime);

  mode = Mode::Ready; print_mode();
}

void loop() {
  // First, read the buttons
  buttonRecord.update();
  buttonPlay.update();

  switch(mode){
    case Mode::Ready:
      // Falling edge occurs when the handset is lifted --> 611 telephone
      if (buttonRecord.fallingEdge()) {
        Serial.println("Handset lifted");
        mode = Mode::Prompting; print_mode();
      }
      else if(buttonPlay.fallingEdge()) {
        //playAllRecordings();
        playLastRecording();
      }
      break;

    case Mode::Prompting:
      // Wait a second for users to put the handset to their ear
      wait(1000);
      // Play the greeting inviting them to record their message
      playWav1.play("greeting.wav");    
      // Wait until the  message has finished playing
//      while (playWav1.isPlaying()) {
      while (!playWav1.isStopped()) {
        // Check whether the handset is replaced
        buttonRecord.update();
        buttonPlay.update();
        // Handset is replaced
        if(buttonRecord.risingEdge()) {
          playWav1.stop();
          mode = Mode::Ready; print_mode();
          return;
        }
        if(buttonPlay.fallingEdge()) {
          playWav1.stop();
          //playAllRecordings();
          playLastRecording();
          return;
        }
        
      }
      // Debug message
      Serial.println("Starting Recording");
      // Play the tone sound effect
      waveform1.begin(beep_volume, 440, WAVEFORM_SINE);
      wait(1250);
      waveform1.amplitude(0);
      // Start the recording function
      startRecording();
      break;

    case Mode::Recording:
      // Handset is replaced
      if(buttonRecord.risingEdge()){
        // Debug log
        Serial.println("Stopping Recording");
        // Stop recording
        stopRecording();
        // Play audio tone to confirm recording has ended
        end_Beep();
      }
      else {
        continueRecording();
      }
      break;

    case Mode::Playing: // to make compiler happy
      break;  

    case Mode::Initialising: // to make compiler happy
      break;  
  }   
  
  MTP.loop();  // This is mandatory to be placed in the loop code.
}

void setMTPdeviceChecks(bool nable)
{
  if (nable)
  {
    MTP.storage()->set_DeltaDeviceCheckTimeMS(MTPcheckInterval);
    Serial.print("En");
  }
  else
  {
    MTP.storage()->set_DeltaDeviceCheckTimeMS((uint32_t) -1);
    Serial.print("Dis");
  }
  Serial.println("abled MTP storage device checks");
}
  

#if defined(INSTRUMENT_SD_WRITE)
static uint32_t worstSDwrite, printNext;
#endif // defined(INSTRUMENT_SD_WRITE)

void startRecording() {
  setMTPdeviceChecks(false); // disable MTP device checks while recording
#if defined(INSTRUMENT_SD_WRITE)
  worstSDwrite = 0;
  printNext = 0;
#endif // defined(INSTRUMENT_SD_WRITE)
  // Find the first available file number
//  for (uint8_t i=0; i<9999; i++) { // BUGFIX uint8_t overflows if it reaches 255  
  for (uint16_t i=0; i<9999; i++) {   
    // Format the counter as a five-digit number with leading zeroes, followed by file extension
    snprintf(filename, 11, " %05d.wav", i);
    // Create if does not exist, do not open existing, write, sync after write
    if (!SD.exists(filename)) {
      break;
    }
  }
  frec = SD.open(filename, FILE_WRITE);
  Serial.println("Opened file !");
  if(frec) {
    Serial.print("Recording to ");
    Serial.println(filename);
    queue1.begin();
    mode = Mode::Recording; print_mode();
    recByteSaved = 0L;
  }
  else {
    Serial.println("Couldn't open file to record!");
  }
}

void continueRecording() {
#if defined(INSTRUMENT_SD_WRITE)
  uint32_t started = micros();
#endif // defined(INSTRUMENT_SD_WRITE)
#define NBLOX 16  
  // Check if there is data in the queue
  if (queue1.available() >= NBLOX) {
    byte buffer[NBLOX*AUDIO_BLOCK_SAMPLES*sizeof(int16_t)];
    // Fetch 2 blocks from the audio library and copy
    // into a 512 byte buffer.  The Arduino SD library
    // is most efficient when full 512 byte sector size
    // writes are used.
    for (int i=0;i<NBLOX;i++)
    {
      memcpy(buffer+i*AUDIO_BLOCK_SAMPLES*sizeof(int16_t), queue1.readBuffer(), AUDIO_BLOCK_SAMPLES*sizeof(int16_t));
      queue1.freeBuffer();
    }
    // Write all 512 bytes to the SD card
    frec.write(buffer, sizeof buffer);
    recByteSaved += sizeof buffer;
  }
  
#if defined(INSTRUMENT_SD_WRITE)
  started = micros() - started;
  if (started > worstSDwrite)
    worstSDwrite = started;

  if (millis() >= printNext)
  {
    Serial.printf("Worst write took %luus\n",worstSDwrite);
    worstSDwrite = 0;
    printNext = millis()+250;
  }
#endif // defined(INSTRUMENT_SD_WRITE)
}

void stopRecording() {
  // Stop adding any new data to the queue
  queue1.end();
  // Flush all existing remaining data from the queue
  while (queue1.available() > 0) {
    // Save to open file
    frec.write((byte*)queue1.readBuffer(), AUDIO_BLOCK_SAMPLES*sizeof(int16_t));
    queue1.freeBuffer();
    recByteSaved += AUDIO_BLOCK_SAMPLES*sizeof(int16_t);
  }
  writeOutHeader();
  // Close the file
  frec.close();
  Serial.println("Closed file");
  mode = Mode::Ready; print_mode();
  setMTPdeviceChecks(true); // enable MTP device checks, recording is finished
}


void playAllRecordings() {
  // Recording files are saved in the root directory
  File dir = SD.open("/");
  
  while (true) {
    File entry =  dir.openNextFile();
    if (strstr(entry.name(), "greeting"))
    {
       entry =  dir.openNextFile();
    }
    if (!entry) {
      // no more files
      entry.close();
      end_Beep();
      break;
    }
    //int8_t len = strlen(entry.name()) - 4;
//    if (strstr(strlwr(entry.name() + (len - 4)), ".raw")) {
//    if (strstr(strlwr(entry.name() + (len - 4)), ".wav")) {
    // the lines above throw a warning, so I replace them with this (which is also easier to read):
    if (strstr(entry.name(), ".wav") || strstr(entry.name(), ".WAV")) {
      Serial.print("Now playing ");
      Serial.println(entry.name());
      // Play a short beep before each message
      waveform1.amplitude(beep_volume);
      wait(750);
      waveform1.amplitude(0);
      // Play the file
      playWav1.play(entry.name());
      mode = Mode::Playing; print_mode();
    }
    entry.close();

//    while (playWav1.isPlaying()) { // strangely enough, this works for playRaw, but it does not work properly for playWav
    while (!playWav1.isStopped()) { // this works for playWav
      buttonPlay.update();
      buttonRecord.update();
      // Button is pressed again
//      if(buttonPlay.risingEdge() || buttonRecord.risingEdge()) { // FIX
      if(buttonPlay.fallingEdge() || buttonRecord.risingEdge()) { 
        playWav1.stop();
        mode = Mode::Ready; print_mode();
        return;
      }   
    }
  }
  // All files have been played
  mode = Mode::Ready; print_mode();
}

void playLastRecording() {
  // Find the first available file number
  uint16_t idx = 0; 
  for (uint16_t i=0; i<9999; i++) {
    // Format the counter as a five-digit number with leading zeroes, followed by file extension
    snprintf(filename, 11, " %05d.wav", i);
    // check, if file with index i exists
    if (!SD.exists(filename)) {
     idx = i - 1;
     break;
      }
  }
      // now play file with index idx == last recorded file
      snprintf(filename, 11, " %05d.wav", idx);
      Serial.println(filename);
      playWav1.play(filename);
      mode = Mode::Playing; print_mode();
      while (!playWav1.isStopped()) { // this works for playWav
      buttonPlay.update();
      buttonRecord.update();
      // Button is pressed again
//      if(buttonPlay.risingEdge() || buttonRecord.risingEdge()) { // FIX
      if(buttonPlay.fallingEdge() || buttonRecord.risingEdge()) {
        playWav1.stop();
        mode = Mode::Ready; print_mode();
        return;
      }   
    }
      // file has been played
  mode = Mode::Ready; print_mode();  
  end_Beep();
}


// Retrieve the current time from Teensy built-in RTC
time_t getTeensy3Time(){
  return Teensy3Clock.get();
}

// Callback to assign timestamps for file system operations
void dateTime(uint16_t* date, uint16_t* time, uint8_t* ms10) {

  // Return date using FS_DATE macro to format fields.
  *date = FS_DATE(year(), month(), day());

  // Return time using FS_TIME macro to format fields.
  *time = FS_TIME(hour(), minute(), second());

  // Return low time bits in units of 10 ms.
  *ms10 = second() & 1 ? 100 : 0;
}

// Non-blocking delay, which pauses execution of main program logic,
// but while still listening for input 
void wait(unsigned int milliseconds) {
  elapsedMillis msec=0;

  while (msec <= milliseconds) {
    buttonRecord.update();
    buttonPlay.update();
    if (buttonRecord.fallingEdge()) Serial.println("Button (pin 0) Press");
    if (buttonPlay.fallingEdge()) Serial.println("Button (pin 1) Press");
    if (buttonRecord.risingEdge()) Serial.println("Button (pin 0) Release");
    if (buttonPlay.risingEdge()) Serial.println("Button (pin 1) Release");
  }
}


void writeOutHeader() { // update WAV header with final filesize/datasize

//  NumSamples = (recByteSaved*8)/bitsPerSample/numChannels;
//  Subchunk2Size = NumSamples*numChannels*bitsPerSample/8; // number of samples x number of channels x number of bytes per sample
  Subchunk2Size = recByteSaved - 42; // because we didn't make space for the header to start with! Lose 21 samples...
  ChunkSize = Subchunk2Size + 34; // was 36;
  frec.seek(0);
  frec.write("RIFF");
  byte1 = ChunkSize & 0xff;
  byte2 = (ChunkSize >> 8) & 0xff;
  byte3 = (ChunkSize >> 16) & 0xff;
  byte4 = (ChunkSize >> 24) & 0xff;  
  frec.write(byte1);  frec.write(byte2);  frec.write(byte3);  frec.write(byte4);
  frec.write("WAVE");
  frec.write("fmt ");
  byte1 = Subchunk1Size & 0xff;
  byte2 = (Subchunk1Size >> 8) & 0xff;
  byte3 = (Subchunk1Size >> 16) & 0xff;
  byte4 = (Subchunk1Size >> 24) & 0xff;  
  frec.write(byte1);  frec.write(byte2);  frec.write(byte3);  frec.write(byte4);
  byte1 = AudioFormat & 0xff;
  byte2 = (AudioFormat >> 8) & 0xff;
  frec.write(byte1);  frec.write(byte2); 
  byte1 = numChannels & 0xff;
  byte2 = (numChannels >> 8) & 0xff;
  frec.write(byte1);  frec.write(byte2); 
  byte1 = sampleRate & 0xff;
  byte2 = (sampleRate >> 8) & 0xff;
  byte3 = (sampleRate >> 16) & 0xff;
  byte4 = (sampleRate >> 24) & 0xff;  
  frec.write(byte1);  frec.write(byte2);  frec.write(byte3);  frec.write(byte4);
  byte1 = byteRate & 0xff;
  byte2 = (byteRate >> 8) & 0xff;
  byte3 = (byteRate >> 16) & 0xff;
  byte4 = (byteRate >> 24) & 0xff;  
  frec.write(byte1);  frec.write(byte2);  frec.write(byte3);  frec.write(byte4);
  byte1 = blockAlign & 0xff;
  byte2 = (blockAlign >> 8) & 0xff;
  frec.write(byte1);  frec.write(byte2); 
  byte1 = bitsPerSample & 0xff;
  byte2 = (bitsPerSample >> 8) & 0xff;
  frec.write(byte1);  frec.write(byte2); 
  frec.write("data");
  byte1 = Subchunk2Size & 0xff;
  byte2 = (Subchunk2Size >> 8) & 0xff;
  byte3 = (Subchunk2Size >> 16) & 0xff;
  byte4 = (Subchunk2Size >> 24) & 0xff;  
  frec.write(byte1);  frec.write(byte2);  frec.write(byte3);  frec.write(byte4);
  frec.close();
  Serial.println("header written"); 
  Serial.print("Subchunk2: "); 
  Serial.println(Subchunk2Size); 
}

void end_Beep(void) {
          waveform1.frequency(523.25);
        waveform1.amplitude(beep_volume);
        wait(250);
        waveform1.amplitude(0);
        wait(250);
        waveform1.amplitude(beep_volume);
        wait(250);
        waveform1.amplitude(0);
        wait(250);
        waveform1.amplitude(beep_volume);
        wait(250);
        waveform1.amplitude(0);
        wait(250);
        waveform1.amplitude(beep_volume);
        wait(250);
        waveform1.amplitude(0);
}

void print_mode(void) { // only for debugging
  Serial.print("Mode switched to: ");
  // Initialising, Ready, Prompting, Recording, Playing
  if(mode == Mode::Ready)           Serial.println(" Ready");
  else if(mode == Mode::Prompting)  Serial.println(" Prompting");
  else if(mode == Mode::Recording)  Serial.println(" Recording");
  else if(mode == Mode::Playing)    Serial.println(" Playing");
  else if(mode == Mode::Initialising)  Serial.println(" Initialising");
  else Serial.println(" Undefined");
}

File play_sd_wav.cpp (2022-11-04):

/* Audio Library for Teensy 3.X
 * Copyright (c) 2014, Paul Stoffregen, paul@pjrc.com
 *
 * Development of this audio library was funded by PJRC.COM, LLC by sales of
 * Teensy and Audio Adaptor boards.  Please support PJRC's efforts to develop
 * open source software by purchasing Teensy or other PJRC products.
 *
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
 * THE SOFTWARE IS PROVIDED "AS IS", WITHOUT WARRANTY OF ANY KIND, EXPRESS OR
 * IMPLIED, INCLUDING BUT NOT LIMITED TO THE WARRANTIES OF MERCHANTABILITY,
 * FITNESS FOR A PARTICULAR PURPOSE AND NONINFRINGEMENT. IN NO EVENT SHALL THE
 * AUTHORS OR COPYRIGHT HOLDERS BE LIABLE FOR ANY CLAIM, DAMAGES OR OTHER
 * LIABILITY, WHETHER IN AN ACTION OF CONTRACT, TORT OR OTHERWISE, ARISING FROM,
 * OUT OF OR IN CONNECTION WITH THE SOFTWARE OR THE USE OR OTHER DEALINGS IN
 * THE SOFTWARE.
 */

#include <Arduino.h>
#include "play_sd_wav.h"
#include "spi_interrupt.h"


#define STATE_DIRECT_8BIT_MONO		0  // playing mono at native sample rate
#define STATE_DIRECT_8BIT_STEREO	1  // playing stereo at native sample rate
#define STATE_DIRECT_16BIT_MONO		2  // playing mono at native sample rate
#define STATE_DIRECT_16BIT_STEREO	3  // playing stereo at native sample rate
#define STATE_CONVERT_8BIT_MONO		4  // playing mono, converting sample rate
#define STATE_CONVERT_8BIT_STEREO	5  // playing stereo, converting sample rate
#define STATE_CONVERT_16BIT_MONO	6  // playing mono, converting sample rate
#define STATE_CONVERT_16BIT_STEREO	7  // playing stereo, converting sample rate
#define STATE_PARSE1			8  // looking for 20 byte ID header
#define STATE_PARSE2			9  // looking for 16 byte format header
#define STATE_PARSE3			10 // looking for 8 byte data header
#define STATE_PARSE4			11 // ignoring unknown chunk after "fmt "
#define STATE_PARSE5			12 // ignoring unknown chunk before "fmt "
#define STATE_PAUSED			13
#define STATE_STOP			14

void AudioPlaySdWavX::begin(void)
{
	state = STATE_STOP;
	state_play = STATE_STOP;
	data_length = 0;
	if (block_left) {
		release(block_left);
		block_left = NULL;
	}
	if (block_right) {
		release(block_right);
		block_right = NULL;
	}
}


bool AudioPlaySdWavX::play(const char *filename)
{
	stop();
	bool irq = false;
	if (NVIC_IS_ENABLED(IRQ_SOFTWARE)) {
		NVIC_DISABLE_IRQ(IRQ_SOFTWARE);
		irq = true;
	}
#if defined(HAS_KINETIS_SDHC)
	if (!(SIM_SCGC3 & SIM_SCGC3_SDHC)) AudioStartUsingSPI();
#else
	AudioStartUsingSPI();
#endif
	wavfile = SD.open(filename);
	if (!wavfile) {
#if defined(HAS_KINETIS_SDHC)
		if (!(SIM_SCGC3 & SIM_SCGC3_SDHC)) AudioStopUsingSPI();
#else
		AudioStopUsingSPI();
#endif
		if (irq) NVIC_ENABLE_IRQ(IRQ_SOFTWARE);
		return false;
	}
	buffer_length = 0;
	buffer_offset = 0;
	state_play = STATE_STOP;
	data_length = 20;
	header_offset = 0;
	state = STATE_PARSE1;
	if (irq) NVIC_ENABLE_IRQ(IRQ_SOFTWARE);
	return true;
}

void AudioPlaySdWavX::stop(void)
{
	bool irq = false;
	if (NVIC_IS_ENABLED(IRQ_SOFTWARE)) {
		NVIC_DISABLE_IRQ(IRQ_SOFTWARE);
		irq = true;
	}
	if (state != STATE_STOP) {
		audio_block_t *b1 = block_left;
		block_left = NULL;
		audio_block_t *b2 = block_right;
		block_right = NULL;
		state = STATE_STOP;
		if (b1) release(b1);
		if (b2) release(b2);
		wavfile.close();
#if defined(HAS_KINETIS_SDHC)
		if (!(SIM_SCGC3 & SIM_SCGC3_SDHC)) AudioStopUsingSPI();
#else
		AudioStopUsingSPI();
#endif
	}
	if (irq) NVIC_ENABLE_IRQ(IRQ_SOFTWARE);
}

void AudioPlaySdWavX::togglePlayPause(void) {
	// take no action if wave header is not parsed OR
	// state is explicitly STATE_STOP
	if(state_play >= 8 || state == STATE_STOP) return;

	// toggle back and forth between state_play and STATE_PAUSED
	if(state == state_play) {
		state = STATE_PAUSED;
	}
	else if(state == STATE_PAUSED) {
		state = state_play;
	}
}

void AudioPlaySdWavX::update(void)
{
	int32_t n;

	// only update if we're playing and not paused
	if (state == STATE_STOP || state == STATE_PAUSED) return;

	// allocate the audio blocks to transmit
	block_left = allocate();
	if (block_left == NULL) return;
	if (state < 8 && (state & 1) == 1) {
		// if we're playing stereo, allocate another
		// block for the right channel output
		block_right = allocate();
		if (block_right == NULL) {
			release(block_left);
			return;
		}
	} else {
		// if we're playing mono or just parsing
		// the WAV file header, no right-side block
		block_right = NULL;
	}
	block_offset = 0;

	//Serial.println("update");

	// is there buffered data?
	n = buffer_length - buffer_offset;
	if (n > 0) {
		// we have buffered data
		if (consume(n)) return; // it was enough to transmit audio
	}

	// we only get to this point when buffer[] is empty
	if (state != STATE_STOP && wavfile.available()) {
		// we can read more data from the file...
		readagain:
		buffer_length = wavfile.read(buffer, sizeof buffer);
		if (buffer_length == 0) goto end;
		buffer_offset = 0;
		bool parsing = (state >= 8);
		bool txok = consume(buffer_length);
		if (txok) {
			if (state != STATE_STOP) return;
		} else {
			if (state != STATE_STOP) {
				if (parsing && state < 8) goto readagain;
				else goto cleanup;
			}
		}
	}
end:	// end of file reached or other reason to stop
	wavfile.close();
#if defined(HAS_KINETIS_SDHC)
	if (!(SIM_SCGC3 & SIM_SCGC3_SDHC)) AudioStopUsingSPI();
#else
	AudioStopUsingSPI();
#endif
	state_play = STATE_STOP;
	state = STATE_STOP;
cleanup:
	if (block_left) {
		if (block_offset > 0) {
			for (uint32_t i=block_offset; i < AUDIO_BLOCK_SAMPLES; i++) {
				block_left->data[i] = 0;
			}
			transmit(block_left, 0);
			if (state < 8 && (state & 1) == 0) {
				transmit(block_left, 1);
			}
		}
		release(block_left);
		block_left = NULL;
	}
	if (block_right) {
		if (block_offset > 0) {
			for (uint32_t i=block_offset; i < AUDIO_BLOCK_SAMPLES; i++) {
				block_right->data[i] = 0;
			}
			transmit(block_right, 1);
		}
		release(block_right);
		block_right = NULL;
	}
}


// https://ccrma.stanford.edu/courses/422/projects/WaveFormat/
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

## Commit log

2022-04-22 Added Fritzing diagram
    [AudioGuestbook.fzz]
2022-08-01 bugfix playWav.isPlaying - change to !playWav.isStopped
    [audio-guestbook.ino]
2022-08-01 Play last recorded file instead of playing ALL the files & bugfix
    [audio-guestbook.ino]
2022-08-02 Compile with 150MHz to save battery power, if powered by power bank or similar
2022-10-27 Use 256-sample audio blocks, and multi-block SD writes
    Also fix the incorrect WAV header chunk sizes
    [audio-guestbook.ino, play_sd_wav.cpp]
2022-10-28 Fix duplicated definition of file buffer
    ...oops, sorry everyone...
    [audio-guestbook.ino]
2022-10-29 Disable MTP unless playback button held down at boot
    MTP appears to interfere with SD card writing, especially the Teensy 4.1 on-board slot. As MTP is only needed when retrieving recordings, it's disabled unless the playback button is pressed at power-up.
    For diagnostic purposes, the worst-case SD card write times can be printed every 0.25s. This is a compile-time option, enabled by defining the INSTRUMENT_SD_WRITE macro. Disabled by default, edit line 42 to enable.
    [audio-guestbook.ino]
2022-11-04 Only disable MTP medium-change check while recording
    Pending fix to usb_mtp.c in cores, this seems to work OK and avoids the "hold button at boot" malarkey.
    [audio-guestbook.ino]
